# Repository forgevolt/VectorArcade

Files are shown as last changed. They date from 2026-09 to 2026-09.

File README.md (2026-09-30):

# VectorArcade

Two handheld game consoles, one firmware. VectorArcade plays **Lunar Lander** and
**Asteroids** - the two vector arcade classics of 1979 - redrawn as line graphics on an
ESP32 with a colour TFT, an analog joystick and I2S sound. The same sketch builds for both
consoles: the **LittleGameConsole** (320x240) and the **TintinRocketShooter** (240x240), whose
housing is modelled on the moon rocket from the Tintin comics.

<table>
  <tr>
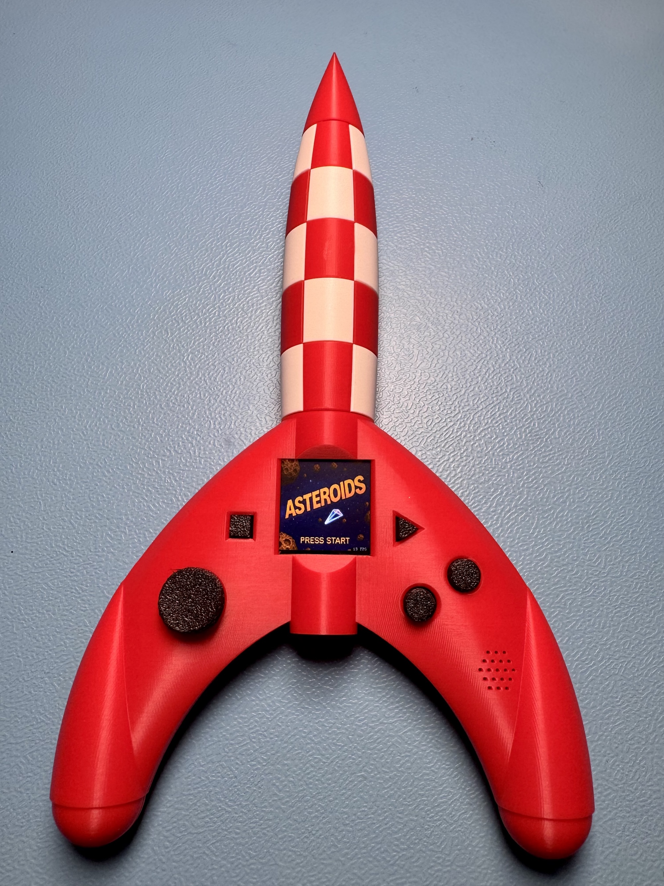
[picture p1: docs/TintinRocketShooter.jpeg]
TintinRocketShooter
    <td></td>
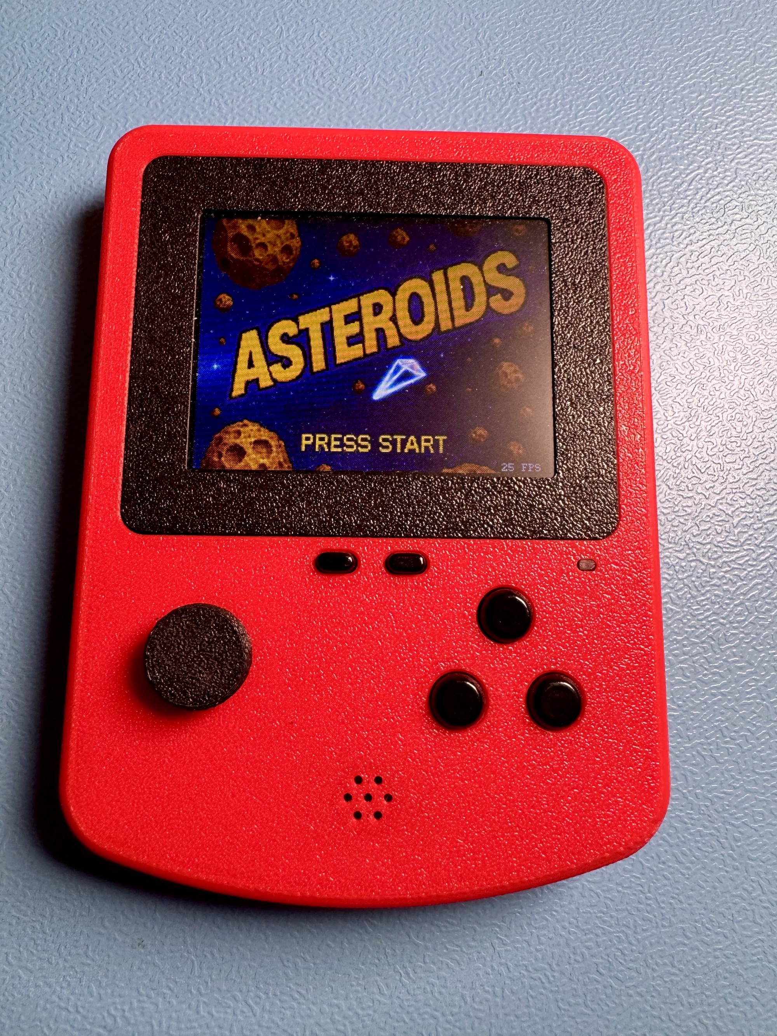
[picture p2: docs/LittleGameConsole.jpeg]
LittleGameConsole
    <td></td>
  </tr>
  <tr>
    <td align="center">TintinRocketShooter</td>
    <td align="center">LittleGameConsole</td>
  </tr>
</table>

## What it does

- **Lunar Lander.** Land the Eagle on one of the pads before the fuel runs out. Four pads
  per attempt carry a bonus of 2x to 5x, and the landing is scored great, good or hard. The
  lunar surface scrolls endlessly in both directions, and the view zooms in close to the
  ground. On the TintinRocketShooter the engine can also be throttled by tilting the console.
- **Asteroids.** Rotate, thrust, fire and jump into hyperspace. Asteroids split when hit,
  a saucer appears from time to time and shoots back, and the high score is kept.
- **Configuration menu.** Joystick calibration, IMU calibration (TintinRocketShooter), sound
  volume, and a wipe-and-reset that clears every stored setting. An FPS display can be
  switched on from the main menu.
- **Sound.** Seven clips mixed by [SoundEngine](https://github.com/forgevolt/SoundEngine),
  loaded from the flash filesystem into PSRAM at startup, or linked into the firmware for
  boards without PSRAM.
- **Battery.** A MAX17048 fuel gauge drives the battery indicator in the menu.
- **Fixed frame rate.** The games run at a steady 25 frames per second.

## Controls

| | Menu | Lunar Lander | Asteroids |
| --- | --- | --- | --- |
| Joystick | up/down: choose | up: engine thrust | left/right: rotate |
| A | open | rotate left | fire |
| B | - | rotate right | thrust |
| Aux | - | abort landing | hyperspace |
| Start | open | start a game | start a game |
| Sel | back | quit the game | quit the game |
| Joystick button | open | - | - |

The TintinRocketShooter has no Aux button: **Start** takes its place during a game (abort
landing, hyperspace). Before a Lunar Lander game, **A** adds fuel and **Start** begins; on the
TintinRocketShooter, left/right first chooses between the joystick and tilting the console
("Gyro") as the throttle.

## Hardware

| Part | LittleGameConsole | TintinRocketShooter |
| --- | --- | --- |
| Controller | ESP32-PICO-MINI-02U, 8 MB flash, 2 MB PSRAM | ESP32-PICO-V3-02, 8 MB flash, 2 MB PSRAM |
| Display | ST7789 320x240, SPI, switched backlight | ST7789 240x240, SPI |
| Buttons | A, B, Aux, Sel, Start, joystick button | A, B, Sel, Start, joystick button |
| Joystick | 2-axis analog | 2-axis analog |
| IMU | - | MPU6050, I2C |
| Fuel gauge | MAX17048, I2C | MAX17048, I2C |
| Charge sense | - | USB present and charger status |
| Audio | MAX98357A, I2S | MAX98357A, I2S |

### Wiring

`software/VectorArcade/boards/<console>/PinMap.h` is the single source of truth for every
GPIO; this table mirrors both.

| Function | Signal | LittleGameConsole | TintinRocketShooter |
| --- | --- | --- | --- |
| Display (SPI) | SCK | 14 | 14 |
| Display (SPI) | MOSI | 12 | 12 |
| Display | DC | 15 | 15 |
| Display | RESET | 13 | 13 |
| Display | backlight | 2 | - |
| I2C (fuel gauge, IMU) | SDA | 22 | 22 |
| I2C (fuel gauge, IMU) | SCL | 21 | 21 |
| I2S (audio) | DOUT | 8 | 8 |
| I2S (audio) | BCLK | 5 | 5 |
| I2S (audio) | LRC / word select | 19 | 19 |
| Button | A | 26 | 4 |
| Button | B | 25 | 7 |
| Button | Aux | 4 | - |
| Button | Sel | 7 | 36 |
| Button | Start | 20 | 20 |
| Joystick | button | 33 | 38 |
| Joystick | X | 37 | 32 |
| Joystick | Y | 38 | 37 |
| Power sense | USB present | - | 26 |
| Power sense | charger status | - | 25 |

Three of these pins need care when wiring or re-laying out a board:

- **GPIO 12 is the flash-voltage strapping pin.** It is latched at reset, and high selects
  1.8 V flash - with 3.3 V flash the board then does not boot. SPI MOSI idles low, which is
  why it works here. Do not fit a pull-up to this line.
- **GPIO 2 must be low or floating at reset**, or the serial bootloader cannot be entered.
  On the LittleGameConsole it switches the backlight, and `setup()` drives it low before
  anything else runs.
- **GPIO 34 to 39 have no internal pull-ups.** On the TintinRocketShooter, Sel (36) and the
  joystick button (38) rely on external pull-ups.

## Repository layout

| | |
|---|---|
| [`software/`](software) | The firmware sketch, and the tools for its sound clips and images |
| [`hardware/`](hardware) | PCBs: EasyEDA projects, Gerbers, schematics |
| [`mechanics/`](mechanics) | Housings: Fusion source, STLs, print profiles |
| [`docs/`](docs) | Photographs of the two consoles |

Each of those has its own README.

## Getting started

1. Install the esp32 core and the libraries (see **Building** below).
2. In `software/VectorArcade/`, copy `BoardSelect.h.template` to `BoardSelect.h` and select
   your console in it.
3. Open `software/VectorArcade/VectorArcade.ino` in the Arduino IDE.
4. Select board *ESP32 Dev Module* with the settings in the table below.
5. Upload, then upload the sound clips once - see
   [Setting up a new console](software/README.md#setting-up-a-new-console).

## Building

Built with the **Arduino IDE** and the **esp32 core 2.0.17** by Espressif Systems (Boards
Manager). The core is pinned on purpose: FabGL, the graphics library, does not build on core
3.x ([FabGL issue #385](https://github.com/fdivitto/FabGL/issues/385)).

### Libraries

Install through the Arduino library manager. These are the versions it is built and tested
against:

| Library | Version | Note |
| --- | --- | --- |
| FabGL | 1.0.9 | display driver, canvas and fonts - GPL-3.0, see [THIRD_PARTY.md](THIRD_PARTY.md) |
| [SoundEngine](https://github.com/forgevolt/SoundEngine) | 1.1.0 | I2S mixing and playback; 1.1.0 is the first version that builds on core 2.x |
| Bounce2 | 2.71 | button debouncing |
| Streaming | 6.3.0 | the `Serial <<` logging |
| Adafruit MAX1704X | 1.0.3 | the fuel gauge |
| Adafruit BusIO | 1.17.4 | installed with Adafruit MAX1704X |
| MPU6050_light | 1.2.1 | by rfetick - the IMU of the TintinRocketShooter; several MPU6050 libraries exist, this is the one used here |

LittleFS, Wire, SPI and Preferences come with the core.

### Board settings

Select **ESP32 Dev Module** and change these settings - four of them differ from the
defaults, and a wrong one fails silently rather than with an error:

| Setting | Value | Note |
| --- | --- | --- |
| Board | **ESP32 Dev Module** | |
| Flash Size | **8MB (64Mb)** | the default is 4MB |
| Flash Frequency | **80MHz** | the default is 40MHz, which halves the flash read speed |
| Flash Mode | **QIO** | |
| PSRAM | **Enabled** | needed for the sound clips on LittleFS |
| Partition Scheme | **8M with spiffs (3MB APP/1.5MB SPIFFS)** | only sets the upload limit; `partitions.csv` defines the layout |
| CPU Frequency | 240MHz | default |
| Erase All Flash Before Sketch Upload | Disabled | default; enabled, it deletes the uploaded sound clips |

`software/VectorArcade/partitions.csv` sits in the sketch folder, and the core uses it in
preference to the Partition Scheme menu: a 6 MB application partition, no OTA, and a
1.875 MB LittleFS partition for the sound clips. The IDE still takes the maximum upload size
from the menu, so uploads are capped at **3,342,336 bytes**; the firmware is about 1.4 MB.
Details, and what to change for boards without PSRAM or with 4 MB flash, are in
[software/README.md](software/README.md).

### Compiler warnings

`software/VectorArcade/build_opt.h` switches on more warnings than the core does:

```
-Wall
-Wextra
-Wdouble-promotion
-Wsign-compare
```

`-Wdouble-promotion` matters on the ESP32, which has no hardware double: it catches float
maths that silently turns into slow double maths. The IDE setting *Compiler warnings: None*
passes `-w`, which hides all of them; to see them, raise that setting or build with
`arduino-cli compile --warnings all`. The firmware builds without a warning from its own
sources; the remaining ones come from the libraries.

## How it runs

One frame every 40 ms (25 FPS): the active game steps its objects by a fixed 40 ms, draws
the frame into FabGL's back buffer, and the buffer is sent to the display over SPI in one
go. That transfer is the largest part of the frame - about 33 ms of the 40 on the
LittleGameConsole - so the other work is kept short, and the background tasks run on the
other core:

| Task | Priority | Core | Rate | Does |
| --- | --- | --- | --- | --- |
| `loopTask` | 1 | 1 | 25 Hz | game logic, joystick, drawing, the frame transfer |
| sound | 1 | 0 | - | mixes and queues the next audio chunk (owned by SoundEngine) |
| `processEvents` | 0 | 0 | 200 Hz | reads and debounces the buttons |

The joystick is read once per frame in the game loop, averaging several ADC readings per
axis against the ESP32's ADC noise. Settings - calibration, volume, high scores, the FPS
display - are stored with Preferences in the `nvs` partition.

## Acknowledgements and trademarks

- **Lunar Lander** and **Asteroids** were released by Atari in 1979. VectorArcade is an
  independent reimplementation, not affiliated with or endorsed by Atari, which owns the
  names. The lunar surface and its landing zones follow the original game's, measured from
  screenshots of it.
- **Tintin** and his moon rocket are creations of Hergé. The TintinRocketShooter's housing
  is an original design based on the rocket from the comics -
  [A lunar project: Tintin's rocket](https://www.tintin.com/en/news/6343/a-lunar-project-tintins-rocket)
  and [The speaking vignette: Tintin's rocket](https://www.tintin.com/en/news/6351/the-speaking-vignette-tintins-rocket).
  The project is not affiliated with or endorsed by the rights holders.
- **Fabrizio Di Vittorio** - [FabGL](https://github.com/fdivitto/FabGL), which does all the
  drawing.
- The sound effects come from [Pixabay](https://pixabay.com/sound-effects/); see
  [THIRD_PARTY.md](THIRD_PARTY.md).

## Licence

MIT - see [LICENSE](LICENSE). The firmware links FabGL, which is GPL-3.0, so a built
firmware image is a combined work under GPL-3.0; the source files here stay MIT, except
`software/tools/img2bitmap.py`, which comes from FabGL. Details, and the licences of all
libraries and assets, are in [THIRD_PARTY.md](THIRD_PARTY.md).

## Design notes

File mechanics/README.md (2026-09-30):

# Housings

The housings of both consoles: Fusion source, print-ready meshes, and the Bambu Studio
projects they were printed from.

| Path | Contents |
|---|---|
| `cad/LittleGameConsole.f3z` | The Fusion source of the LittleGameConsole, as an archive containing the whole assembly |
| `cad/TintinRocketShooter.f3d` | The Fusion source of the TintinRocketShooter |
| `stl/LittleGameConsole.stl` | Print-ready mesh of the LittleGameConsole: 7 bodies in one file, 93 x 127 x 23 mm overall |
| `stl/TintinRocketShooter.stl` | Print-ready mesh of the TintinRocketShooter: 13 bodies in one file, 150 x 45 x 244 mm overall |
| `print-profiles/LittleGameConsole/` | Bambu Studio projects, one per part |
| `print-profiles/TintinRocketShooter/` | Bambu Studio projects, one per part or group of parts, some in two materials |

The TintinRocketShooter's housing is an original design based on Tintin's moon rocket from
Hergé's comics; the red and white checks are printed as separate tiles.

## The parts

Taken from the projects in `print-profiles/`. Every project was sliced for one Bambu Lab
printer and nozzle, named in the table.

### LittleGameConsole

| Project | Part | Printer, nozzle | Layer | Walls | Infill | Material |
|---|---|---|---|---|---|---|
| `LittleGameConsole_Top0.2.3mf` | top shell | H2D, 0.2 mm | 0.10 mm | 4 | 15% | PLA |
| `LittleGameConsole_Bottom_90Deg.3mf` | bottom shell, standing on edge (90°) | H2D, 0.4 mm | 0.12 mm | 4 | 15% | PETG-CF |
| `LittleGameConsole_Bottom_30Deg.3mf` | bottom shell, tilted (30°) | H2D, 0.4 mm | 0.16 mm | 2 | 15% | PETG-CF |
| `Buttons.3mf` | action and control buttons | H2D, 0.4 mm | 0.12 mm | 4 | 50% | ABS |

The two bottom-shell projects are the same part in two print orientations; print one of them.

### TintinRocketShooter

| Project | Part | Printer, nozzle | Layer | Walls | Infill | Material |
|---|---|---|---|---|---|---|
| `TinTinRocket-Lower-H2D-ABS-GF.3mf` | lower body | H2D, 0.4 mm | 0.12 mm | 6 | 15% | ABS-GF |
| `TinTinRocket-Lower-H2D-PLA-GF.3mf` | lower body | H2D, 0.4 mm | 0.12 mm | 6 | 15% | ABS-GF (see below) |
| `TinTinRocket-Upper-H2D-ABS-GF ABS-Support.3mf` | upper body | H2D, 0.4 mm | 0.12 mm | 6 | 15% | ABS-GF |
| `TinTinRocket-Upper-H2D-PLA-GF Support.3mf` | upper body | H2D, 0.4 mm | 0.12 mm | 6 | 15% | PLA-GF |
| `TinTinRocket-Top-H2D-ABS-GF ABS-Support.3mf` | top | H2D, 0.4 mm | 0.08 mm | 6 | 15% | ABS-GF |
| `TinTinRocket-Top-H2D-PLA-GF Support.3mf` | top | H2D, 0.4 mm | 0.12 mm | 6 | 15% | PLA-GF |
| `RocketShooterLower.3mf` | lower body | X1 Carbon, 0.2 mm | 0.06 mm | 6 | 15% | PLA |
| `RocketShooterUpper.3mf` | upper body | X1 Carbon, 0.2 mm | 0.06 mm | 6 | 15% | PLA |
| `RocketTop.3mf` | top | X1 Carbon, 0.2 mm | 0.06 mm | 6 | 15% | PLA |
| `Tiles.3mf` | the checker tiles, rows 1 to 5 | X1 Carbon, 0.2 mm | 0.06 mm | 6 | 15% | PLA |
| `SelectStartBtn.3mf` | Select and Start buttons | X1 Carbon, 0.2 mm | 0.06 mm | 6 | 15% | PLA |
| `JoyTopCover.3mf` | joystick cap | X1 Carbon, 0.4 mm | 0.2 mm | 2 | 15% | TPU |
| `Battery.3mf` | battery end pieces, plus and minus | X1 Carbon, 0.2 mm | 0.06 mm | 6 | 15% | PLA |
| `Stand.3mf` | stand | X1 Carbon, 0.4 mm | 0.12 mm | 3 | 15% | PLA |

The body - lower part, upper part and top - comes in two sets of projects: `TinTinRocket-*`
for an H2D with a 0.4 mm nozzle, in glass-filled ABS or PLA, and `RocketShooter*` /
`RocketTop` for an X1 Carbon with a 0.2 mm nozzle, in PLA. Print one set.

## Opening the CAD

`LittleGameConsole.f3z` is a Fusion archive rather than a single `.f3d` part - open it with
*File → Open* in Fusion, which unpacks the design and its components.
`TintinRocketShooter.f3d` opens directly.

There is no STEP export here. If you want to modify a housing without a Fusion licence, a
STEP export is the thing to ask for; the STLs are fine for printing but carry no editable
geometry.

## About `print-profiles/`

These are Bambu Studio projects: a full copy of the mesh plus the slicer state, so each is
specific to one printer and one filament, and the larger ones run to tens of megabytes. They
are here as a reference for anyone with the same machine. On any other printer, the STLs
plus the tables above carry the same information in a form your own slicer can use.

**This folder still needs a cleanup.** It holds the projects as they were used, and not all
of them are consistent yet:

- `TinTinRocket-Lower-H2D-PLA-GF.3mf` is currently an exact copy of the ABS-GF project, so
  it prints in ABS-GF too. A PLA-GF project for the lower body is still to come.
- The TintinRocketShooter's body is covered twice, by the `TinTinRocket-*` projects for the
  H2D and the `RocketShooter*` / `RocketTop` projects for the X1 Carbon.
- Some file names contain spaces, and the names do not follow one pattern.

Until then, check part, printer and filament in Bambu Studio before printing.

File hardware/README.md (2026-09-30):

# PCBs

The custom boards of both consoles: everything needed to have them made, and to change them.

| Path | Contents |
|---|---|
| `easyeda/ProPrj_LittleGameConsole_2026-09-30.epro2` | LittleGameConsole: the editable EasyEDA Pro project - schematic and layout |
| `easyeda/ProPrj_TintinRocketShooter_2026-09-30.epro2` | TintinRocketShooter: the same |
| `gerber/Gerber_LittleGameConsolePCB_2026-09-30.zip` | LittleGameConsole: fabrication files, zipped as a fab expects them |
| `gerber/Gerber_PCB_TintinRocketShooter_2026-09-30.zip` | TintinRocketShooter: the same |
| `schematic_LittleGameConsole.pdf` | LittleGameConsole: the schematic as a document, readable without EasyEDA (6 sheets) |
| `schematic_TintinRocketShooter.pdf` | TintinRocketShooter: the same (7 sheets) |

The EasyEDA projects and the Gerber archives carry their export date in the file name, so a
later revision can sit beside these rather than silently replacing them.

## Ordering a board

Upload the Gerber archive of the console as it is - a standard Gerber and drill set. Nothing
in the design depends on a particular fab.

If you revise a layout, tag this repository when you order from it. A year later, "which
files made the board in my hand" then has an answer the tree alone cannot give.

## What is on the boards

From the schematics, the parts worth naming:

| Function | LittleGameConsole | TintinRocketShooter |
|---|---|---|
| Controller | ESP32-PICO-MINI-02U | ESP32-PICO-V3-02 |
| USB to serial, for flashing and the Serial Monitor | CP2102N | CP2102N |
| ESD protection of the USB lines | USBLC6-2SC6 | USBLC6-2SC6 |
| Li-ion charger | MCP73831 | MCP73831 |
| 3.3 V regulator | LD39200PUR, 2 A LDO | NCP167BMX330TBG, LDO |
| Battery fuel gauge | MAX17048 | MAX17048 |
| I2S class-D amplifier | MAX98357A | MAX98357A |

The display, the joystick and the buttons connect to the board; the GPIO of every signal is
in the wiring table of the top-level README, which mirrors each console's `PinMap.h`. The
same section names the three pins that need care in a new layout: GPIO 12 (flash voltage),
GPIO 2 (boot mode) and the input-only GPIO 34 to 39.

The schematic is the authority for what was actually built.

## Known errors on the TintinRocketShooter board

- **The battery connector sits too close to the display** and cannot be fitted. The
  battery's wires are soldered directly to the board instead.
- **The ESP32 reset button sits too close to the display**, which would keep it pressed. It
  is not fitted.
- **The joystick is exposed to electrostatic discharge without its cap.** Touching the bare
  joystick can discharge into the board, and the firmware then hangs. Always fit the cap
  (`JoyTopCover` in [`mechanics/`](../mechanics)). A revision should add ESD protection to
  the joystick lines, or ground the joystick's metal housing.

A revision of this board should move the battery connector and the reset button clear of
the display.

## Ideas for the next revision

None of these is a fault - both boards work as built. They are traps for whoever reworks or
re-lays-out a board, and improvements collected while writing the firmware.

### Pins

1. **GPIO 12 - flash voltage.** GPIO 12 is latched at reset and selects the flash voltage;
   high means 1.8 V, and with 3.3 V flash the board then does not boot. Today it carries SPI
   MOSI, which idles low. Keep it free of anything that can pull it high - or fix the
   voltage for good with `espefuse.py set_flash_voltage 3.3V`, after checking with
   `espefuse.py summary` whether the module has already done so (`XPD_SDIO_FORCE`). Burning
   the eFuse is irreversible and must match the module's flash.
2. **Display bus on its native pins.** The ST7789 is driven at 40 MHz because MOSI on
   GPIO 12 is not one of HSPI's native pins, which routes the whole bus through the GPIO
   matrix. Swapping MOSI and RESET (12 ↔ 13) puts every signal on its native pin and allows
   80 MHz - raising the full-frame limit from about 32 to about 65 frames per second at
   320x240. 80 MHz overclocks the panel (the ST7789 specifies 62.5 MHz), so test it on
   several units. After the swap, RESET sits on GPIO 12: a pull-up on the panel's reset
   line would then stop the board from booting, so decide this together with item 1.
3. **I2S clocks off GPIO 5 and 19.** These are the Arduino defaults for SPI `SS` and `MISO`.
   Nothing calls `SPI.begin()` today, but a library that does would take over both I2S
   clocks.
4. **GPIO 2 and the backlight** (LittleGameConsole). GPIO 2 must be low or floating at reset
   for the serial bootloader. Driving the backlight from it works because `setup()` pulls it
   low first; a backlight circuit with a pull-up would break flashing.
5. **Buttons on GPIO 34 to 39** (TintinRocketShooter). These pins have no internal pull-ups,
   so Sel (36) and the joystick button (38) depend on external resistors. Keep them
   deliberately, or move the buttons to pins with internal pull-ups.

The I2C pins 21 and 22 are the reverse of the Arduino defaults. The firmware handles this
by calling `Wire.begin(cI2C_SDA, cI2C_SCL)` before any library starts the bus; a board that
uses the default order would not depend on that.

### Charging

6. **Charge sense for the LittleGameConsole.** The TintinRocketShooter shows a "+" at the
   battery while charging, from two signals: USB present, and the charger's STAT output.
   The LittleGameConsole has neither - its GPIO 25 and 26 are buttons. A revision needs two
   free pins, the analog one on ADC1 (GPIO 32 to 39). The firmware is ready: add the pins to
   `PinMap.h` and set `BOARD_HAS_CHARGE_SENSE()` to 1 in `Board.h`. Whether the MAX17048's
   own charge-rate reading can replace this without a hardware change is still being
   tested.
7. **Read all three states of STAT.** The MCP73831's STAT output is low while charging, high
   when charging is complete, and high-impedance with no input power or no battery. A
   digital input cannot tell high-impedance from high. Bias the sense node with two
   100 kΩ resistors to 3.3 V and ground, feed STAT through a **75 kΩ series resistor**, and
   add 100 nF to ground; one ADC reading then gives about 0.99 V (charging), 1.65 V
   (high-impedance) or 3.0 V (complete). The series resistor matters: the charger runs
   from USB, so STAT high is about 5 V, beyond the ESP32's 3.6 V maximum. Schematic:
   [`STAT_TriState.svg`](STAT_TriState.svg). On the current TintinRocketShooter board,
   check whether STAT already reaches GPIO 25 through a divider or series resistor.

STAT three-state sense

### Larger changes

8. **ESP32-S3 with PSRAM.** Its DMA can read PSRAM, so a full-screen frame buffer in PSRAM
   could be sent to the display while the next frame is drawn; the display bus goes on
   native pins as in item 2; and it brings a faster core, a better ADC and native USB. The
   cost: FabGL does not support the S3, so the graphics move to TFT_eSPI or LovyanGFX, and
   the pin map starts over - different strapping pins (0, 3, 45, 46), native USB on GPIO
   19 and 20, octal PSRAM reserving GPIO 35 to 37, ADC1 on GPIO 1 to 10. The esp32 core
   2.0.17 supports the S3.
9. **A dedicated ADC for the joystick.** The ESP32's ADC is flat near both ends, bent above
   about 2.5 V, noisy, and not ratiometric to the potentiometers' supply; the firmware
   compensates with calibration, averaging and an expo curve. An **MCP3208** (or the
   4-channel MCP3204) on its own SPI pins, with `VREF` tied to the potentiometer supply,
   gives 12 linear, ratiometric bits in microseconds, plus spare channels for the battery
   or the STAT node. An **ADS1115** needs no new pins - it joins the I2C bus at 0x48 to
   0x4B - but converts at most about 400 times a second per axis and adds traffic to the
   bus the IMU is read on. On an ESP32-S3, measure the built-in ADC first. **Hall-effect
   joysticks** fix the other half of the problem - wear, drift and dead spots of the
   potentiometers - and work with either choice. In the firmware, `Joystick2Axis` reads
   through a single function, so an external ADC is a second implementation behind a
   `Board.h` setting.

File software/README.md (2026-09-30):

# Software

| Path | What |
|---|---|
| `VectorArcade/` | The firmware. One sketch for both consoles |
| `tools/wav2h.py` | Turns the WAV files into headers for the linked build, and writes their fingerprint |
| `tools/img2bitmap.py` | Converts an image into a FabGL `Bitmap` in C++ source, as used for the splash screens. From FabGL, GPL-3.0 |

## `VectorArcade/` - the firmware

| Files | Responsibility |
| --- | --- |
| `VectorArcade.ino` | setup of display, fuel gauge, IMU, filesystem and menu; the 25 FPS loop |
| `Menu.*`, `MenuItem.*`, `MenuPage.*` | the main menu, its entries and the configuration page |
| `DisplayObject.*` | base class of everything on screen, text and instruction helpers |
| `InputController.*`, `Joystick2Axis.*` | the buttons, debounced in their own task, and the joystick |
| `LunarLander.*`, `Eagle.*`, `LunarSurface.*`, `Camera.h`, `LunarLanderSounds.h` | Lunar Lander: game states, the lander, the endless surface, the scrolling and zooming view |
| `Asteroids.*`, `AsteroidsGameObjects.*`, `AsteroidsSounds.h` | Asteroids: game states, ship, shots, asteroids and saucer |
| `SoundClips.*` | loads the clips from LittleFS and checks their fingerprint |
| `JoystickCalibration.*`, `IMUCalibration.*`, `SoundVolume.*`, `WipeAndReset.*`, `FPSToggle.*` | the configuration entries |
| `BatteryStatus.*`, `IMUStatus.*` | the battery indicator and the IMU readout in the menu |
| `MathUtilities.*` | 2D and 3D vector maths |
| `Version.h` | the firmware version |
| `BoardSelect.h.template` | the console to build for, and the sound source (see below) |
| `Board.h`, `PinMap.h`, `Layout.h`, `AsteroidsSplash.h` | forward to the selected console's files in `boards/` |
| `boards/<console>/` | per console: GPIO (`PinMap.h`), display and features (`Board.h`), screen positions (`Layout.h`), the Asteroids splash image |
| `data/` | the sound clips as WAV files, and their fingerprint `sounds.id` |
| `sounds/` | the same clips as headers, generated by `wav2h.py` |
| `build_opt.h` | extra compiler warnings |
| `partitions.csv` | 6 MB app + 1.875 MB LittleFS; overrides the Tools menu |

### Choosing the console

The console is selected in `BoardSelect.h`. That file is not tracked by git, so switching
consoles never shows up as a change. After cloning, copy `BoardSelect.h.template` to
`BoardSelect.h` and set exactly one of these to 1:

```cpp
#define BOARD_IS_LITTLEGAMECONSOLE()    1
#define BOARD_IS_TINTINROCKETSHOOTER()  0
```

The same file holds one build option, where the sound clips come from:

```cpp
#define SOUNDS_FROM_LITTLEFS()          1
```

- **1** (default): the WAV files are read from the `littlefs` partition into PSRAM at
  startup. The firmware is smaller, and a firmware upload does not rewrite the sounds. Needs
  PSRAM, and the files uploaded once (below).
- **0**: the clips are linked into the firmware from `sounds/*.h`. Works without PSRAM and
  without a file upload, at about 0.4 MB more firmware.

The build prints which console and which sound source it is building for.

### Partition table

`partitions.csv` sits in the sketch folder, and the core uses it in preference to the
Partition Scheme menu:

| Name | Type | Offset | Size | |
| --- | --- | --- | --- | --- |
| nvs | data | 0x9000 | 20 KB | stored settings: calibration, volume, high scores |
| otadata | data | 0xE000 | 8 KB | |
| factory | app | 0x10000 | 6 MB | the firmware, single slot, no OTA |
| littlefs | data | 0x610000 | 1.875 MB | the sound clips |
| coredump | data | 0x7F0000 | 64 KB | a crash dump, readable with `espcoredump.py` |

The `littlefs` partition keeps the subtype `spiffs`: ESP-IDF 4.4, which core 2.0.17 is built
on, has no LittleFS subtype, and LittleFS finds the partition by its label.

The Partition Scheme menu still matters for one thing: the IDE takes the maximum upload size
from it, so uploads are capped at **3,342,336 bytes** although the partition holds 6 MB.

### Setting up a new console

1. Choose the console as above, compile and upload. The upload writes the partition table
   from `partitions.csv` together with the firmware.
2. Let it boot once with the Serial Monitor open (115200 baud). The empty `littlefs`
   partition cannot be mounted yet, so the firmware formats it and reports
   `LittleFS: partition cannot be mounted - formatting it as LittleFS`. A partition that
   holds another filesystem (SPIFFS, FAT) is formatted the same way, and its files are lost.
3. Upload the contents of `data/` - the seven WAV files and `sounds.id` - into the root of
   the LittleFS partition, for example with the browser tool
   [ESPConnect](https://github.com/thelastoutpostworkshop/ESPConnect). File names are
   case-sensitive. Then restart.
4. At startup the firmware compares `sounds.id` with the fingerprint compiled into it and
   reports `LittleFS: sound files match`, or tells you to upload `data/` again.

Later firmware uploads keep the files, as long as *Erase All Flash Before Sketch Upload*
stays disabled.

### Changing a sound

`data/*.wav` is the single source of the sound clips: 16-bit PCM WAV, mono, 11,025 Hz.
After changing, adding or removing a file, run

```
python3 software/tools/wav2h.py
```

It regenerates `sounds/*.h` for the linked build and writes a new fingerprint into
`data/sounds.id` and `sounds/SoundsId.h`. Then rebuild, and upload `data/` again, including
`sounds.id`. `wav2h.py --check` only reports whether anything is out of date. The script
needs nothing beyond the Python 3 standard library.

### Boards without PSRAM, or with 4 MB flash

- Without PSRAM, build with `SOUNDS_FROM_LITTLEFS()` set to 0. A LittleFS build without
  PSRAM is refused at compile time.
- `partitions.csv` is laid out for **8 MB** flash, so a 4 MB module needs a different
  partition table. The linked build is about 1.84 MB, so on 4 MB it fits only a partition
  scheme with a ~3 MB application ("Huge APP", no OTA), not the default 1.25 MB one.
- Replace or remove `partitions.csv` accordingly. While it is present it overrides the
  Partition Scheme menu, and the IDE's size check still uses the menu's maximum, so select a
  scheme whose application size matches.

## `tools/img2bitmap.py` - images for the display

The firmware cannot read image files: every picture is compiled in as a FabGL `Bitmap`, a
byte array plus its size and pixel format. `img2bitmap.py` is FabGL's own converter,
included unmodified. It needs Python 3 and Pillow (`pip install pillow`):

```
python3 software/tools/img2bitmap.py AsteroidsSplash.png -s 320 240 -f1 > AsteroidsSplash.h
```

| Option | |
|---|---|
| `-s width height` | resize to this size - 320 240 for the LittleGameConsole, 240 240 for the TintinRocketShooter |
| `-f0` / `-f1` / `-f2` | pixel format: RGBA2222 (64 colours, the default), RGBA8888, or 1-bit monochrome |
| `-d` | dither, for RGBA2222 |
| `-t x y` | take the colour of this pixel as transparent |
| `-o0` / `-o1` | output as C++ source (the default) or as a plain hex string |

The array and the bitmap are named after the input file, so `AsteroidsSplash.png` gives
exactly the `AsteroidsSplash_data` and `AsteroidsSplash` that `boards/<console>/AsteroidsSplash.h`
declares. The splash screens use RGBA8888: their colour gradients band or turn grainy in
64 colours.

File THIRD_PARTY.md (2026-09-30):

# Third-party licences

The files in this repository are MIT licensed (see LICENSE), except
`software/tools/img2bitmap.py`, which comes from FabGL (below). The firmware builds against
the libraries below. None of them are redistributed here - each is installed
through the Arduino library manager or comes with the esp32 core, and keeps its own licence.

| Library | Licence | Used for |
| --- | --- | --- |
| FabGL | GPL-3.0 | the display driver, the canvas and the fonts |
| SoundEngine | MIT | I2S mixing and playback |
| Bounce2 | MIT | button debouncing |
| Streaming | LGPL-2.1-or-later | the `Serial <<` logging |
| Adafruit MAX1704X | BSD | the battery fuel gauge |
| Adafruit BusIO | MIT | I2C access for the fuel gauge library |
| MPU6050_light | MIT | the IMU of the TintinRocketShooter |
| esp32 core 2.0.17 | LGPL-2.1 (Arduino core), Apache-2.0 (ESP-IDF) | the platform, including LittleFS, Wire, SPI and Preferences |

SoundEngine is written for this project and published separately, under the same MIT
licence as this repository: [SoundEngine](https://github.com/forgevolt/SoundEngine).

## FabGL

[FabGL](https://github.com/fdivitto/FabGL) by Fabrizio Di Vittorio does all the drawing:
the ST7789 driver, the double-buffered canvas and the fonts. It is licensed under
**GPL-3.0**.

The firmware cannot be built without linking FabGL, so a **built firmware image is a
combined work governed by GPL-3.0**, even though the firmware's own files are MIT.
Unlike the LGPL (see Streaming below), the GPL has no relinking exception that would let the
binary keep a more permissive licence. In practice:

| | |
| --- | --- |
| The firmware source in this repository | MIT. FabGL itself is not redistributed here, only named as a dependency. |
| A built `.bin`, or a console with the firmware on it | Conveyed under GPL-3.0. The corresponding source is this public repository together with FabGL's own. |
| Reusing files from this repository elsewhere | MIT, unaffected - as long as FabGL is not part of what is carried across. |

`software/tools/img2bitmap.py` is FabGL's image converter (`tools/img2bitmap/` in the
FabGL repository), included unmodified. It is part of FabGL and therefore GPL-3.0, not MIT;
it is a separate tool that runs on the PC, so it does not become part of the firmware.

FabGL's own notices stay intact, and nothing in this repository describes FabGL as MIT.

## Streaming

`Streaming.h` by Mikal Hart is used for logging throughout the firmware. The LGPL does not
affect the licence of this project, but it asks that anyone who receives a binary can relink
it against a modified version of the library. Complete source is published here, so a
recipient can modify Streaming and rebuild.

## Sound effects

The seven clips in `software/VectorArcade/data/` (and the headers generated from them in
`software/VectorArcade/sounds/`) come from [Pixabay](https://pixabay.com/sound-effects/),
under the [Pixabay Content License](https://pixabay.com/service/license-summary/). It allows
use and modification, commercially too, without attribution; it does not allow selling or
distributing a clip on its own. Here each one is part of the game, and all of them were
trimmed, looped and re-encoded for it.

| Clip | Source |
| --- | --- |
| `RocketEngine.wav` | [Looking straight into a burning rocket engine](https://pixabay.com/sound-effects/film-special-effects-sfx-looking-straight-into-a-burning-rocket-engine-sound-effect-283448/) |
| `Explosion.wav`, `FuelAlarm.wav`, `Pew.wav`, `PewSaucer.wav`, `SaucerAlert.wav`, `SmallExplosion.wav` | Pixabay; the individual pages are no longer known |

The menu click, beep and signal sounds are generated by SoundEngine.

## Splash screens

The Asteroids splash screens (`software/VectorArcade/boards/*/AsteroidsSplash.h`) are
AI-generated artwork made for this project, with the game's own vector ship drawn into
them. They are covered by the MIT licence of this repository.

## Names

Lunar Lander and Asteroids are names of arcade games released by Atari in 1979; Tintin and
his moon rocket are creations of Hergé. VectorArcade is an independent project, not
affiliated with or endorsed by either rights holder. The games are reimplemented from their
published gameplay, and the TintinRocketShooter's housing is an original design based on the
rocket from the comics.

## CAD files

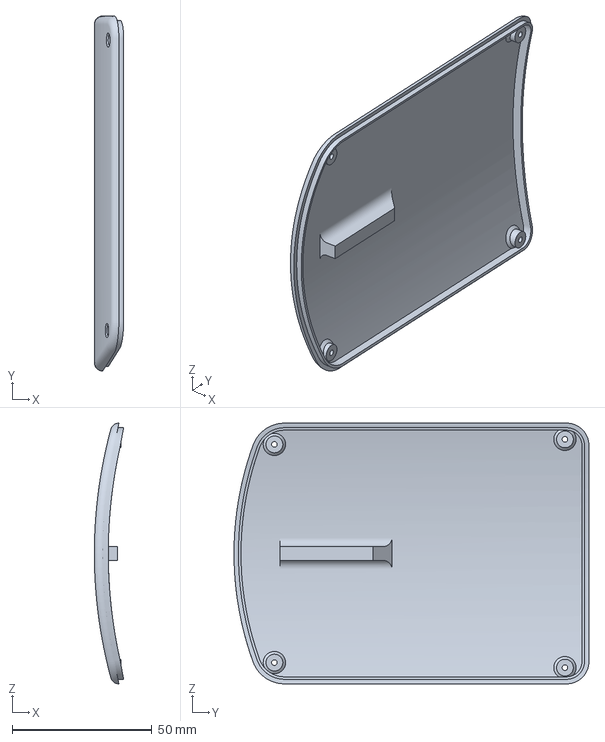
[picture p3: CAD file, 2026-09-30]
mechanics/print-profiles/LittleGameConsole/LittleGameConsole_Bottom_90Deg.3mf
10.5 x 126.9 x 93.2 mm

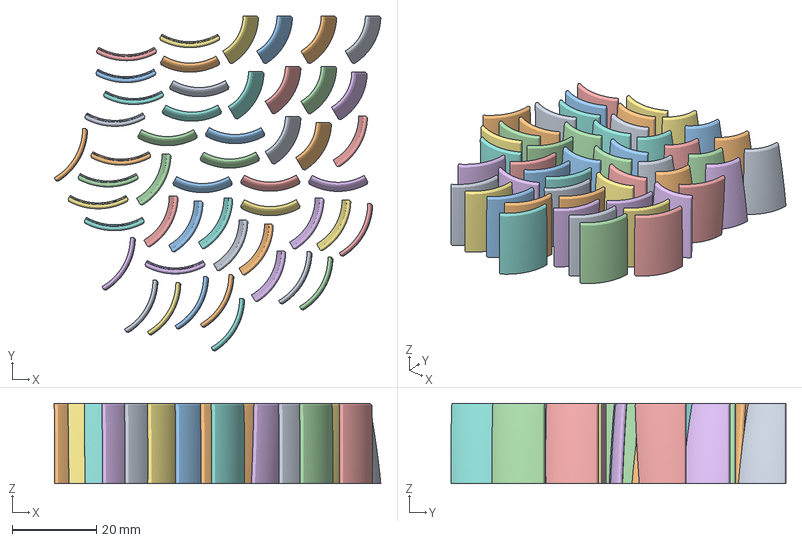
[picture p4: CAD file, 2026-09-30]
mechanics/print-profiles/TintinRocketShooter/Tiles.3mf
77.6 x 79.5 x 19.0 mm
TileRow1.step x 10
TileRow2.step x 10
TileRow5.step x 10
TileRow4.step x 10
TileRow3.step x 10

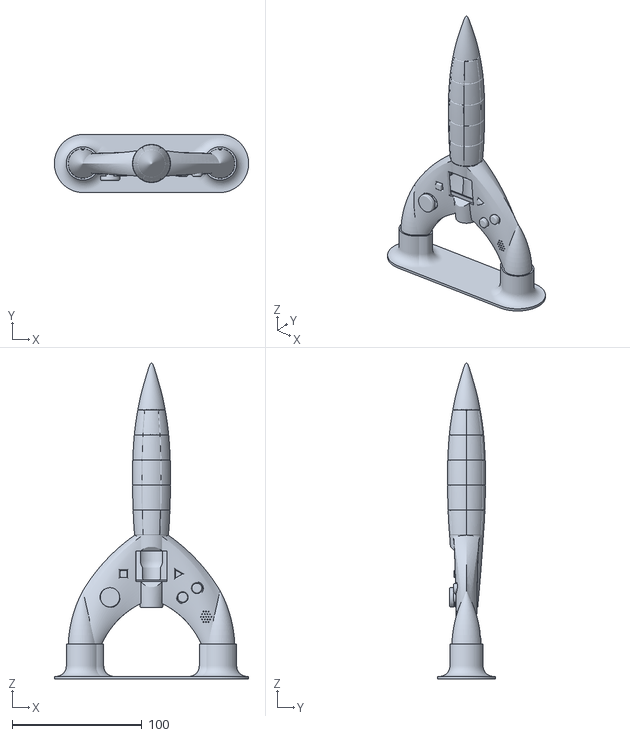
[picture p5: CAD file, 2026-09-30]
mechanics/stl/TintinRocketShooter.stl
150.0 x 45.0 x 243.9

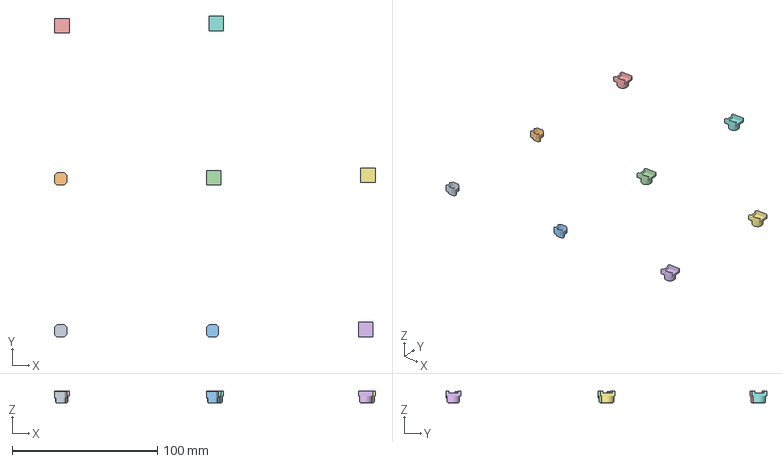
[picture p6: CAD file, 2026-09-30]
mechanics/print-profiles/LittleGameConsole/Buttons.3mf
220.8 x 220.8 x 8.30 mm
ControlButton.stl x 3
ActionButton.stl x 5

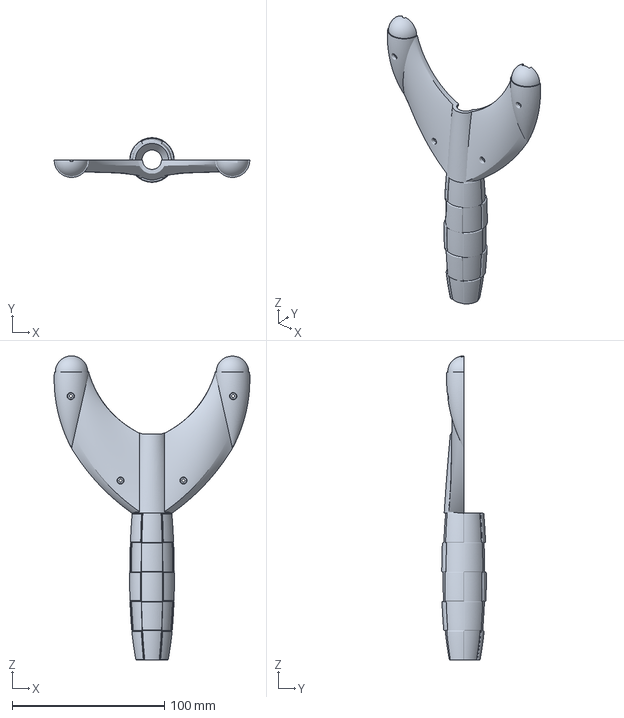
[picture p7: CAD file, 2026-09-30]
mechanics/print-profiles/TintinRocketShooter/RocketShooterLower.3mf
128.7 x 29.3 x 200.0 mm

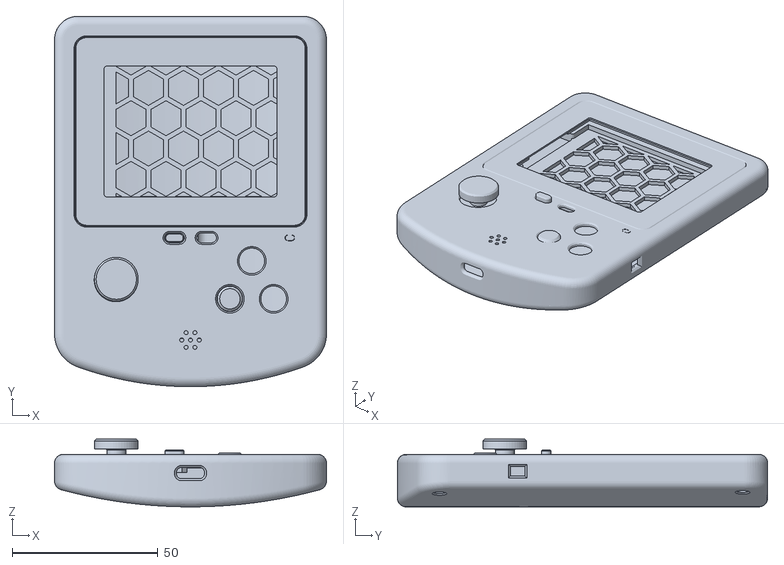
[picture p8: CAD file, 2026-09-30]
mechanics/stl/LittleGameConsole.stl
93.2 x 126.9 x 23.2

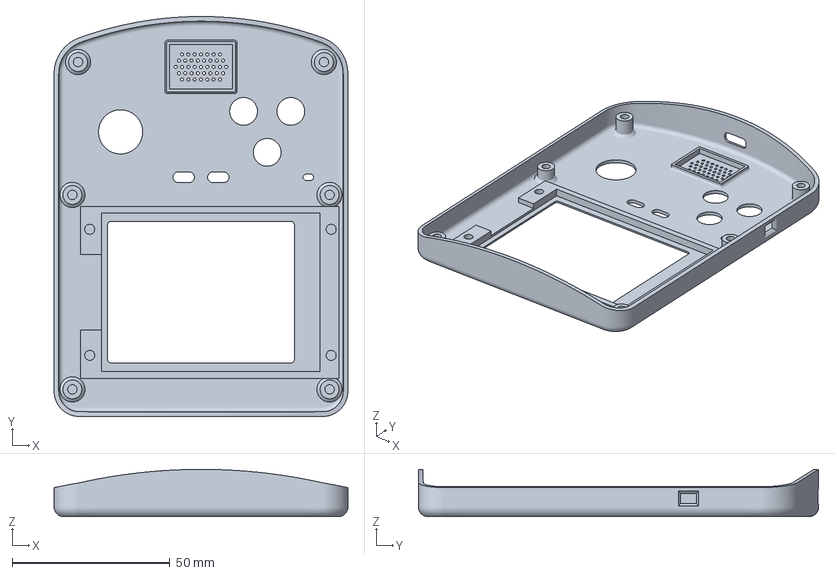
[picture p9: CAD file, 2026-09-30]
mechanics/print-profiles/LittleGameConsole/LittleGameConsole_Top0.2.3mf
93.2 x 126.9 x 15.0 mm

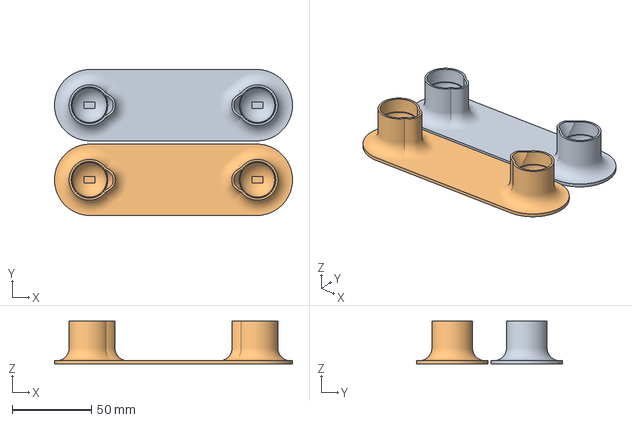
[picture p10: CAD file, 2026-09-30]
mechanics/print-profiles/TintinRocketShooter/Stand.3mf
150.0 x 92.0 x 27.0 mm
Stand.step x 2

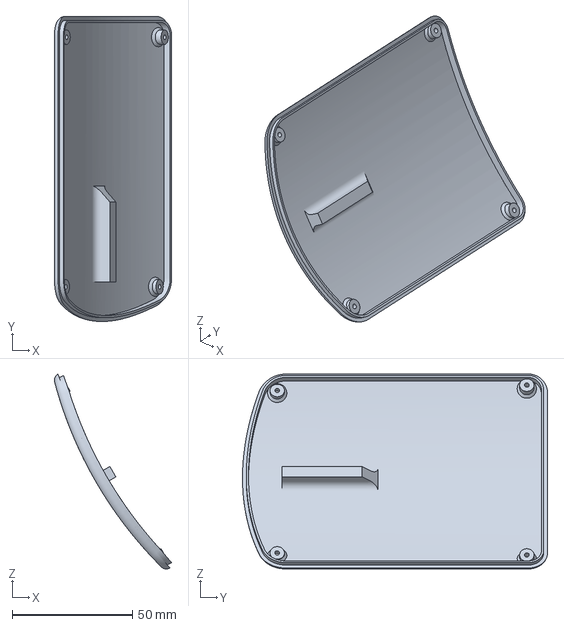
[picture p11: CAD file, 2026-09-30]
mechanics/print-profiles/LittleGameConsole/LittleGameConsole_Bottom_30Deg.3mf
48.8 x 126.9 x 81.1 mm

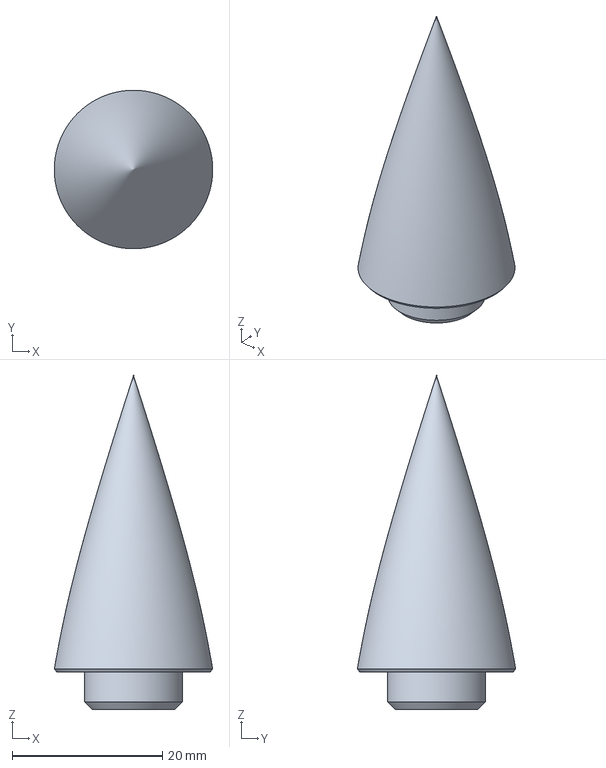
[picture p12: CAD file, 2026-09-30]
mechanics/print-profiles/TintinRocketShooter/TinTinRocket-Top-H2D-ABS-GF ABS-Support.3mf
21.1 x 21.1 x 44.4 mm

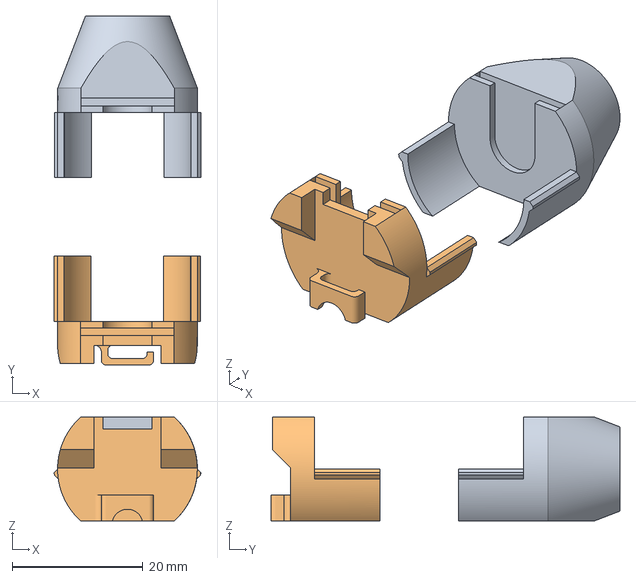
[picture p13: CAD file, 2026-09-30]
mechanics/print-profiles/TintinRocketShooter/Battery.3mf
22.5 x 53.5 x 15.9 mm
BatteryPlusEnd.stl
BatteryNegEnd.stl

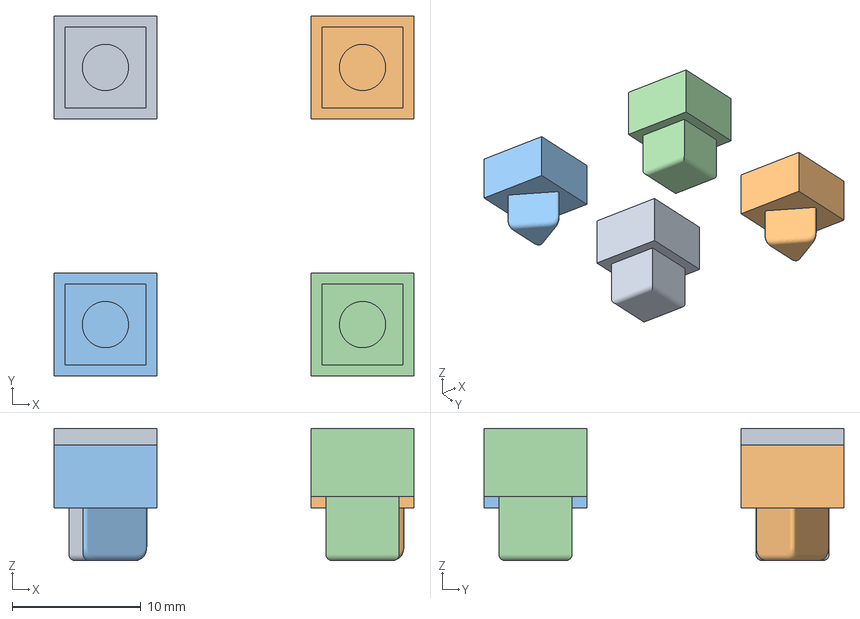
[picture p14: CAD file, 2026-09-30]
mechanics/print-profiles/TintinRocketShooter/SelectStartBtn.3mf
28.0 x 28.0 x 10.3 mm
SelectBtn.stl x 2
StartBtn.stl x 2

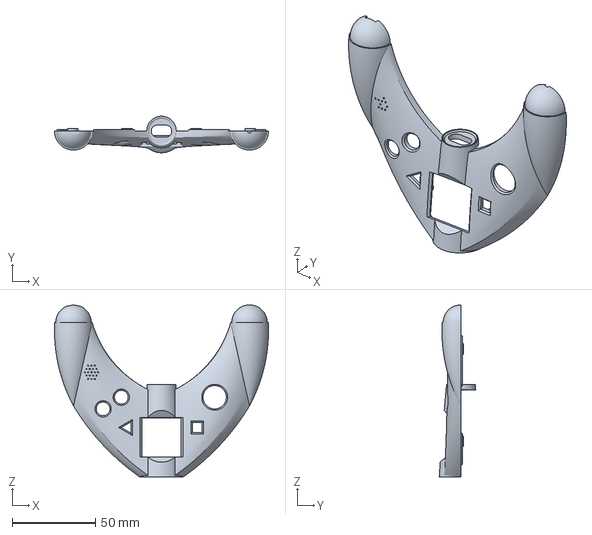
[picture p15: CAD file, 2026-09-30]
mechanics/print-profiles/TintinRocketShooter/TinTinRocket-Upper-H2D-PLA-GF Support.3mf
128.7 x 22.0 x 103.4 mm

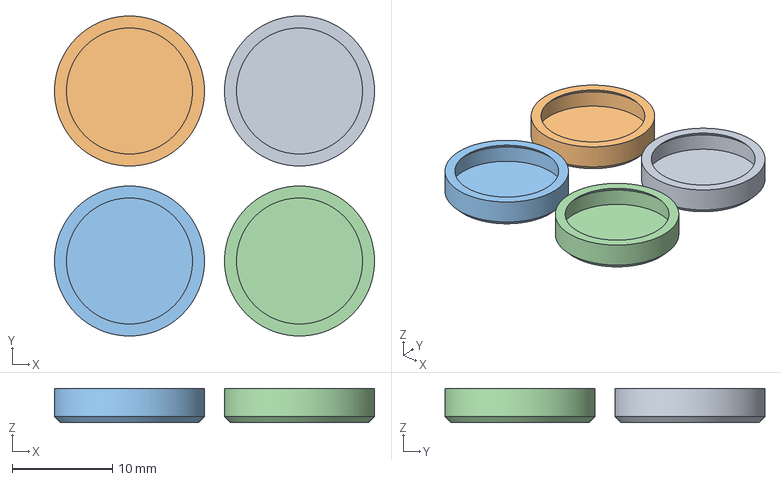
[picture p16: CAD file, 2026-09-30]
mechanics/print-profiles/TintinRocketShooter/JoyTopCover.3mf
32.0 x 32.0 x 3.40 mm
JoyTopCover.stl x 4

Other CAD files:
mechanics/print-profiles/TintinRocketShooter/TinTinRocket-Upper-H2D-ABS-GF ABS-Support.3mf
mechanics/print-profiles/TintinRocketShooter/TinTinRocket-Top-H2D-PLA-GF Support.3mf
mechanics/print-profiles/TintinRocketShooter/RocketShooterUpper.3mf
mechanics/print-profiles/TintinRocketShooter/RocketTop.3mf
mechanics/cad/LittleGameConsole.f3z

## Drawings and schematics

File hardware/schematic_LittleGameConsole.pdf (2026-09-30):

Drawn
VER

Create Date

PAGE | OF

Schematic

Update Date

SIZE

Page

2025-04-14

# 2025-04-14 LittleGameConsole

## Overview

# Hobbyist

## Christoph Streit

1 | A4

# Microcontroller

# Audio

Sheet: USB&Serial | Sheet: ESP32
2 | 3

# Sheet: Audio

5

I/O

# Sheet: Connectors / IO

6

# Power

# Sheet: Power

4

# USB to Serial USB

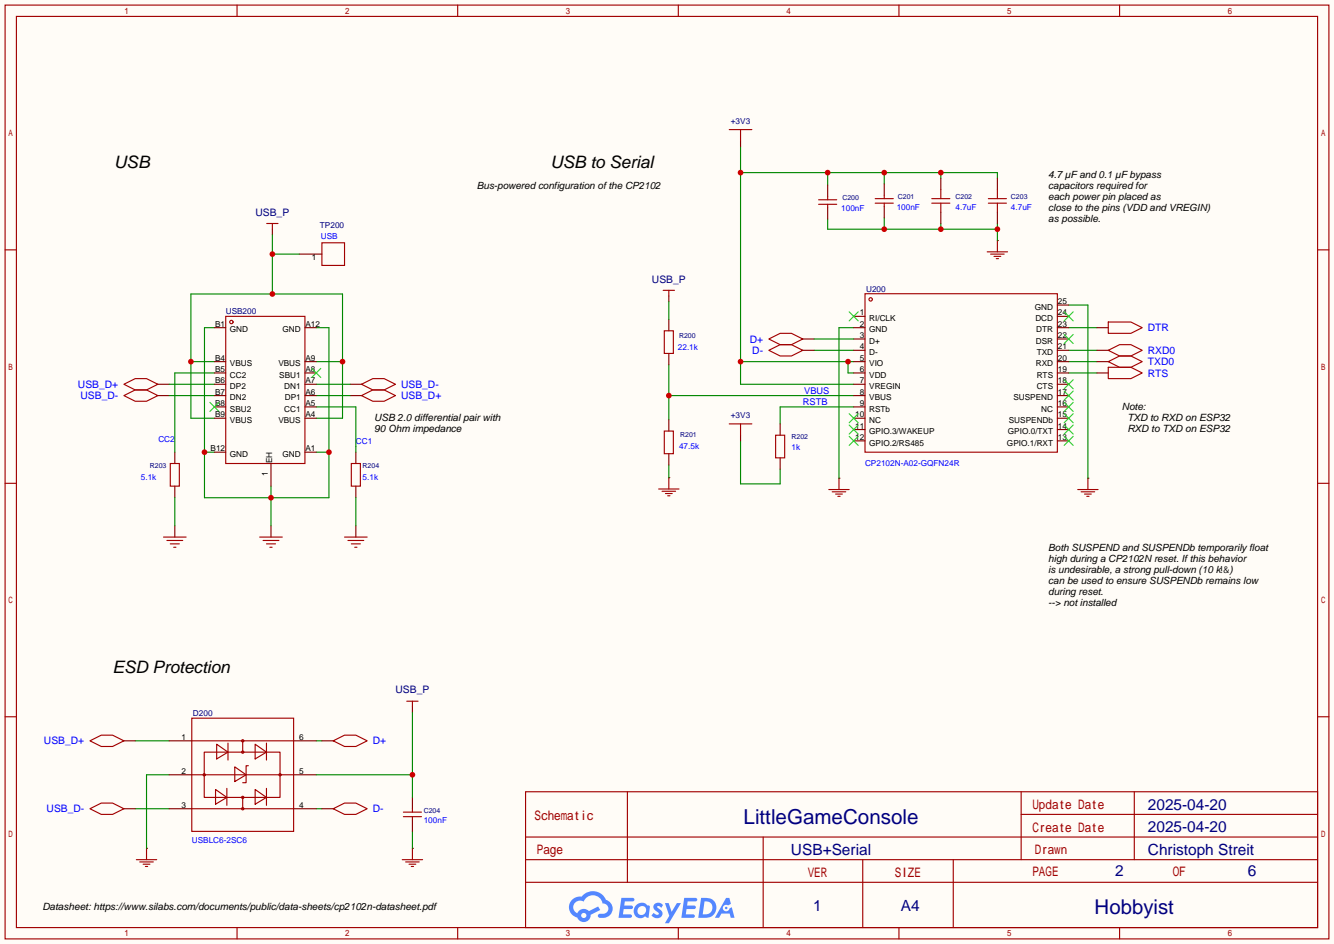
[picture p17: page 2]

4.7 µF and 0.1 µF bypass
capacitors required for
each power pin placed as
close to the pins (VDD and VREGIN)
as possible.

Bus-powered configuration of the CP2102

Note:
TXD to RXD on ESP32
RXD to TXD on ESP32

Both SUSPEND and SUSPENDb temporarily float
high during a CP2102N reset. If this behavior
is undesirable, a strong pull-down (10 k!&)
can be used to ensure SUSPENDb remains low
during reset.
--> not installed

Datasheet: https://www.silabs.com/documents/public/data-sheets/cp2102n-datasheet.pdf

# ESP32-PICO-MINI-02U

# NC 25 IO20 26 IO7 27 IO8 28 IO5 29 RXD0 30 TXD0 31 NC 32 IO19 33 IO22 34 IO21 35 GND 36

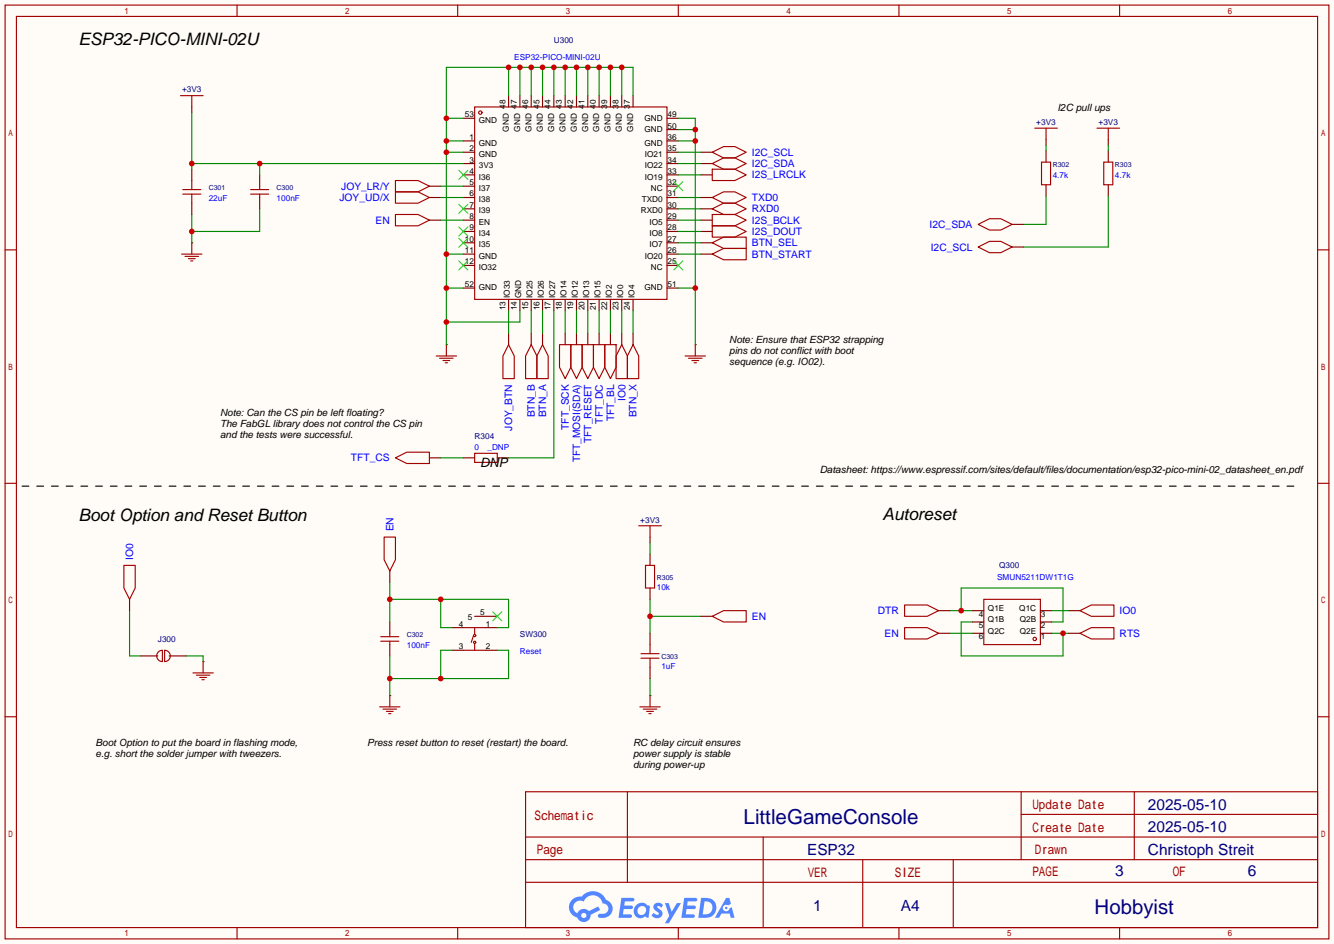
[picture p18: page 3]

Note: Ensure that ESP32 strapping
pins do not conflict with boot
sequence (e.g. IO02).

Note: Can the CS pin be left floating?
The FabGL library does not control the CS pin
and the tests were successful.

https://www.espressif.com/sites/default/files/documentation/esp32-pico-mini-02_datasheet_en.pdf

Boot Option to put the board in flashing mode,
e.g. short the solder jumper with tweezers.

Press reset button to reset (restart) the board.

RC delay circuit ensures
power supply is stable
during power-up

# Automatic Switchover

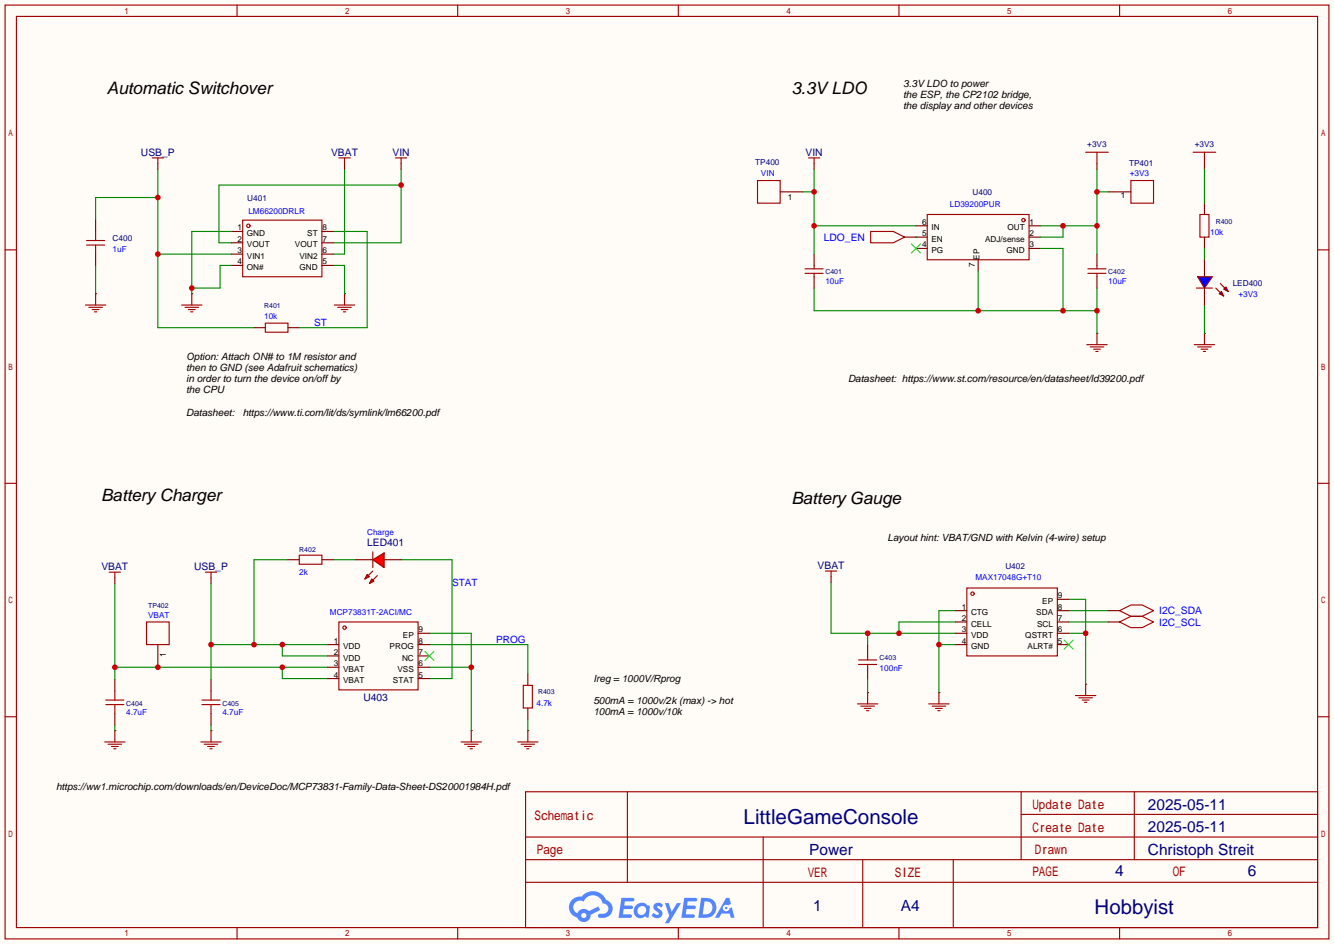
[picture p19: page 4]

the ESP, the CP2102 bridge,
the display and other devices

Option: Attach ON# to 1M resistor and
then to GND (see Adafruit schematics)
in order to turn the device on/off by
the CPU
Datasheet: https://www.ti.com/lit/ds/symlink/lm66200.pdf

Datasheet: https://www.st.com/resource/en/datasheet/ld39200.pdf

Layout hint: VBAT/GND with Kelvin (4-wire) setup

https://ww1.microchip.com/downloads/en/DeviceDoc/MCP73831-Family-Data-Sheet-DS20001984H.pdf

## Gain Selection

## Amplifier

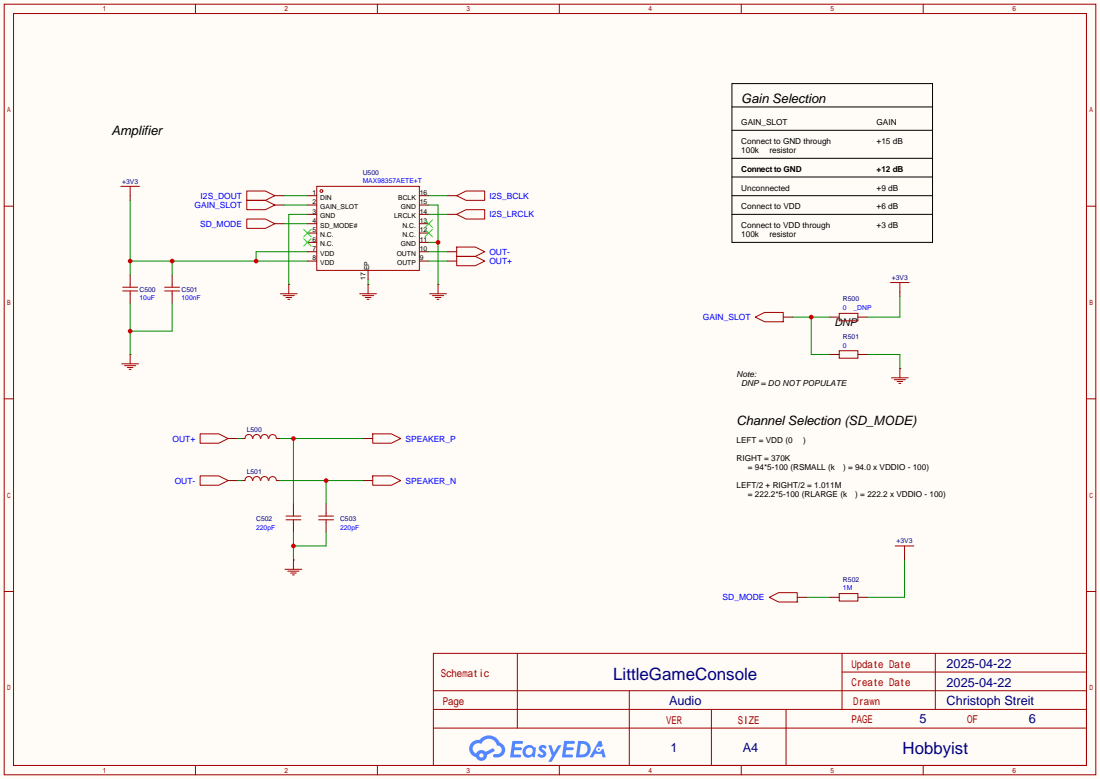
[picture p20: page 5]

Connect to GND through
100k resistor
Connect to GND
Unconnected
Connect to VDD
Connect to VDD through

Note:
DNP = DO NOT POPULATE

Display | On/Off | M2 Mounting Holes

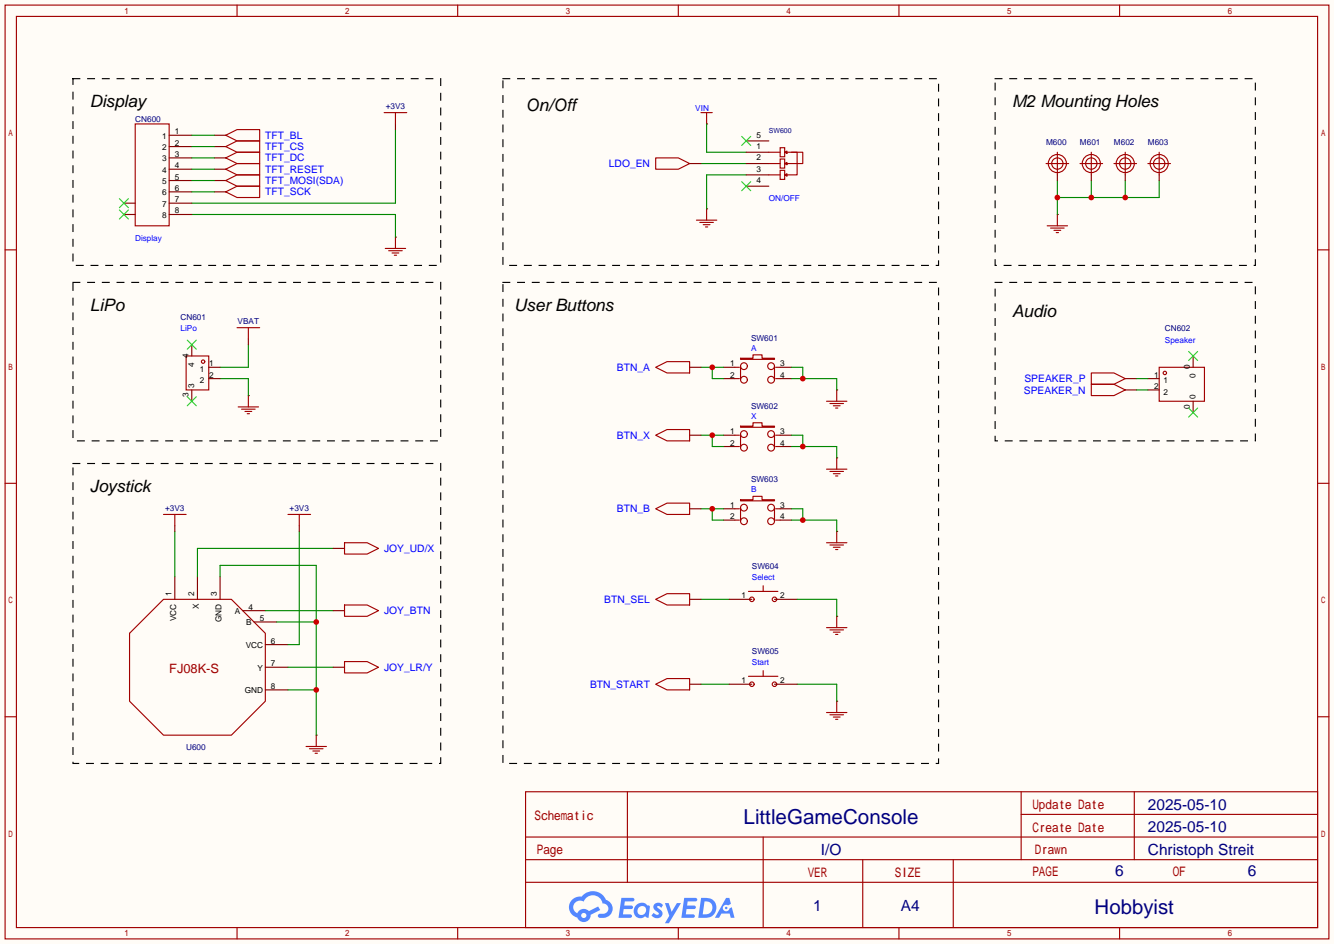
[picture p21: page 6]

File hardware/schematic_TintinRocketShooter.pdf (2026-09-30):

A | A
B | B
C | C
D | D

## TITLE: REV:

## Date:

## Sheet: Drawn By:

## Company:

RocketShooter_from_STD | 1.0

2023-06-25

christoph.streit

Hobbyist

# Microcontroller

# Audio

Sheet: USB&Serial | Sheet: ESP32

# [1] Overview

2 | 3

# IMU

6

Sheet: Audio | Sheet: IMU

5

I/O

# Sheet: Connectors / IO

7

4

# Sheet: Power

# Power

# Sheet: Power

4

# 3.3V LDO

# [4] Power

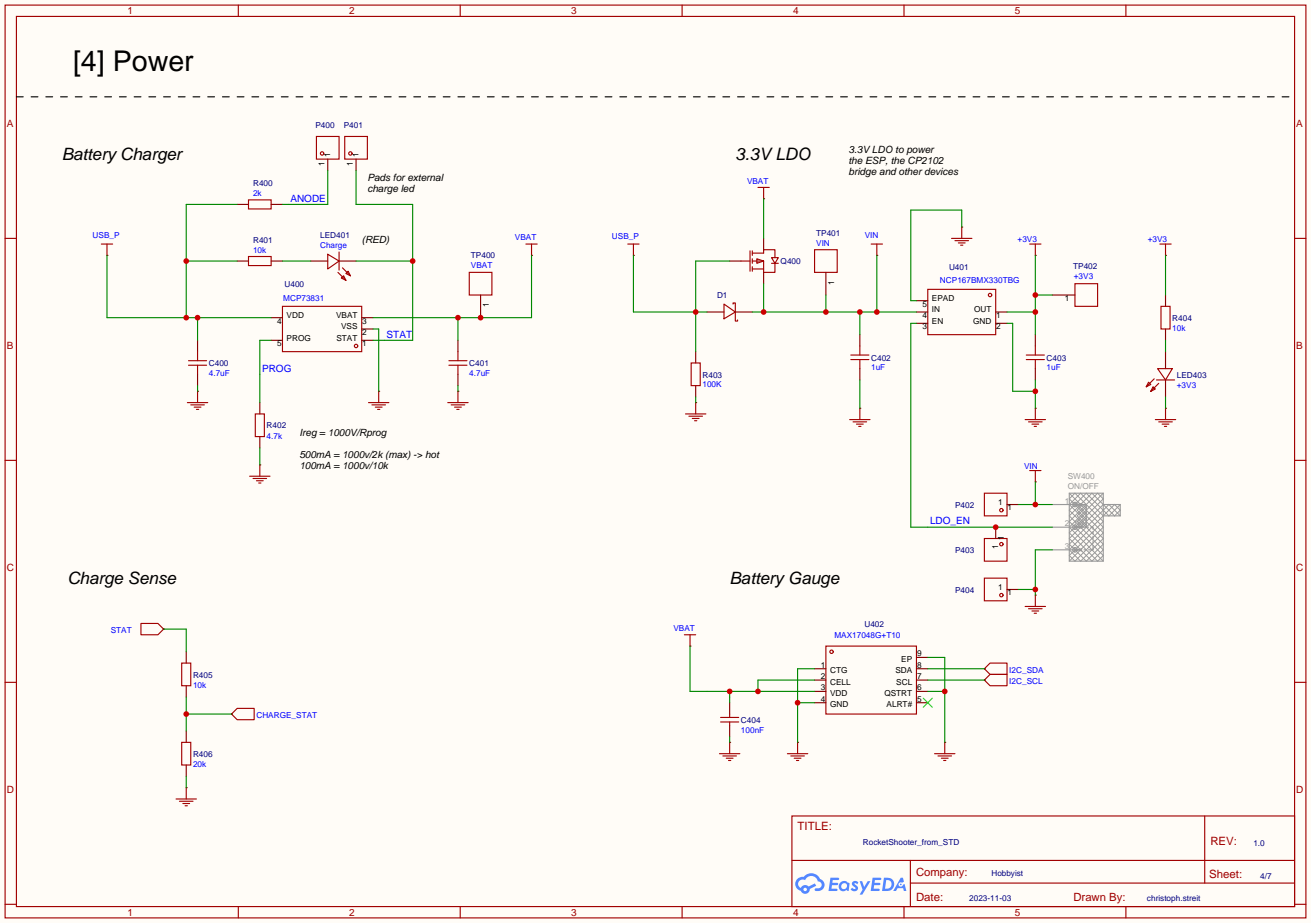
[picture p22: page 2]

3.3V LDO to power
the ESP, the CP2102
bridge and other devices

# [5] Audio

# Gain Selection

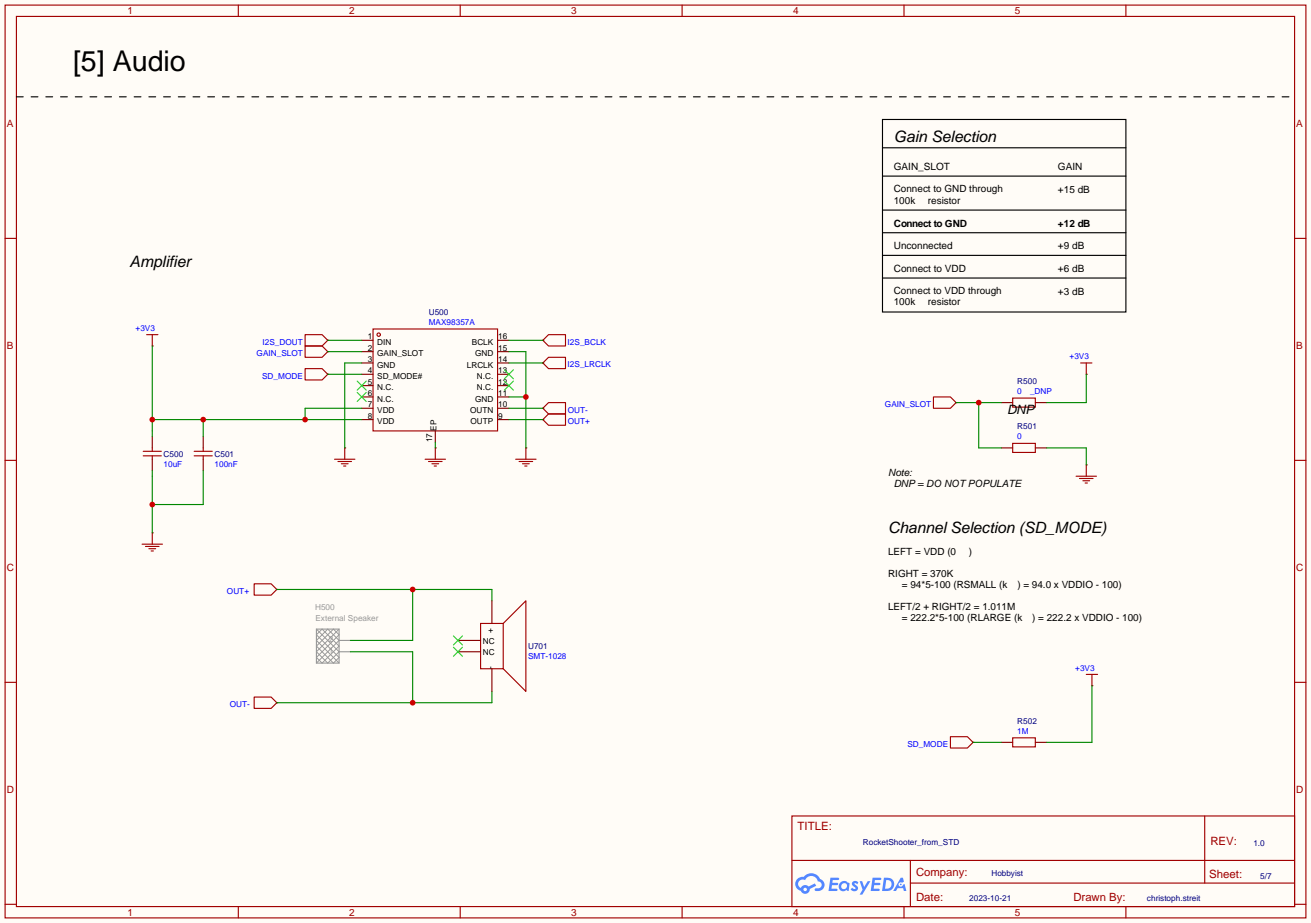
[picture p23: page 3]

Connect to GND through
100k resistor
Connect to GND
Unconnected
Connect to VDD
Connect to VDD through

Note:
DNP = DO NOT POPULATE

USB | USB to Serial

# [2] USB & Serial Bridge

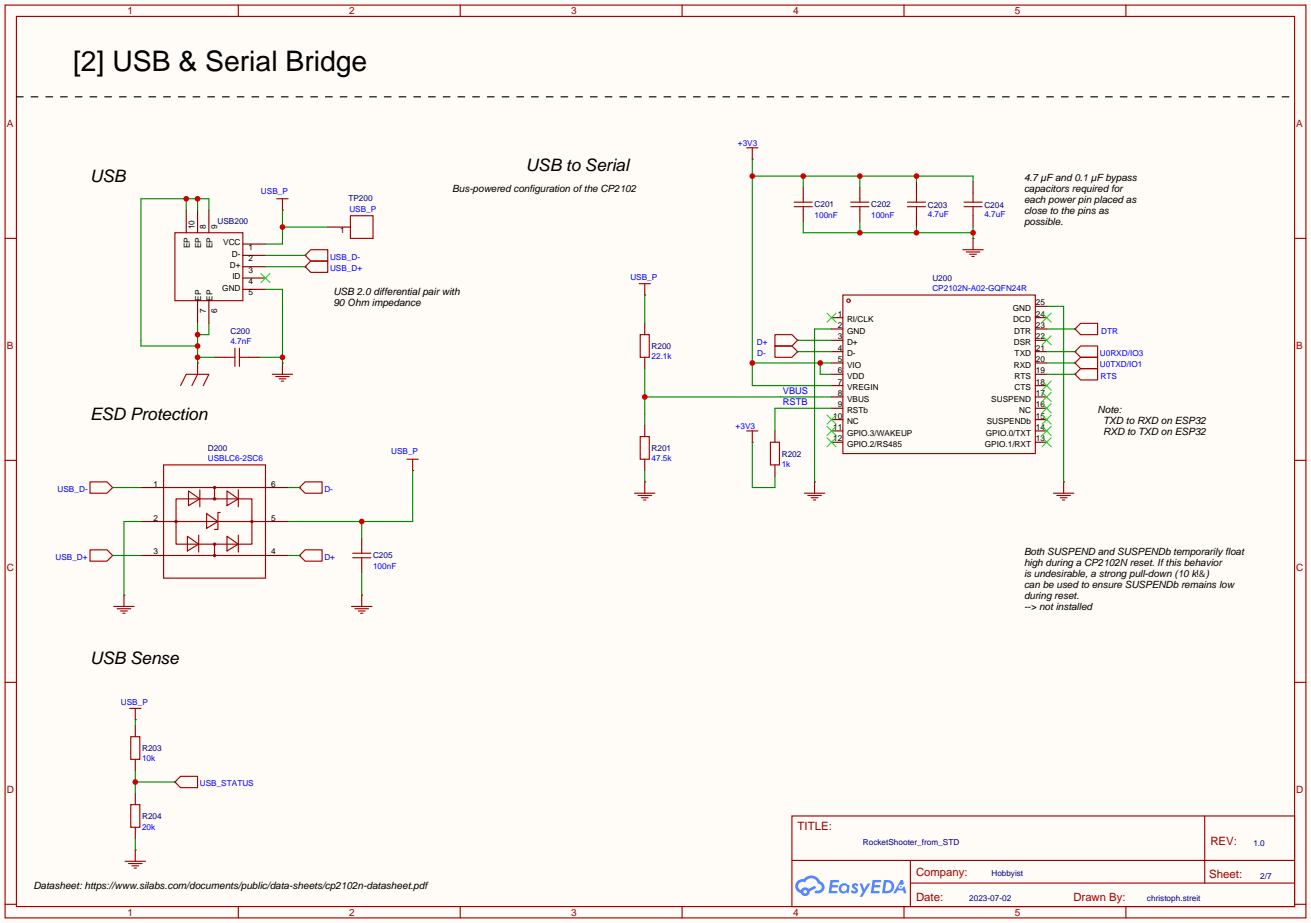
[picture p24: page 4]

4.7 µF and 0.1 µF bypass
capacitors required for
each power pin placed as
close to the pins as
possible.

Bus-powered configuration of the CP2102

Note:
TXD to RXD on ESP32
RXD to TXD on ESP32

Both SUSPEND and SUSPENDb temporarily float
high during a CP2102N reset. If this behavior
is undesirable, a strong pull-down (10 k!&)
can be used to ensure SUSPENDb remains low
during reset.
--> not installed

Datasheet: https://www.silabs.com/documents/public/data-sheets/cp2102n-datasheet.pdf

# ESP32 PICO V3-02

# [3] ESP32

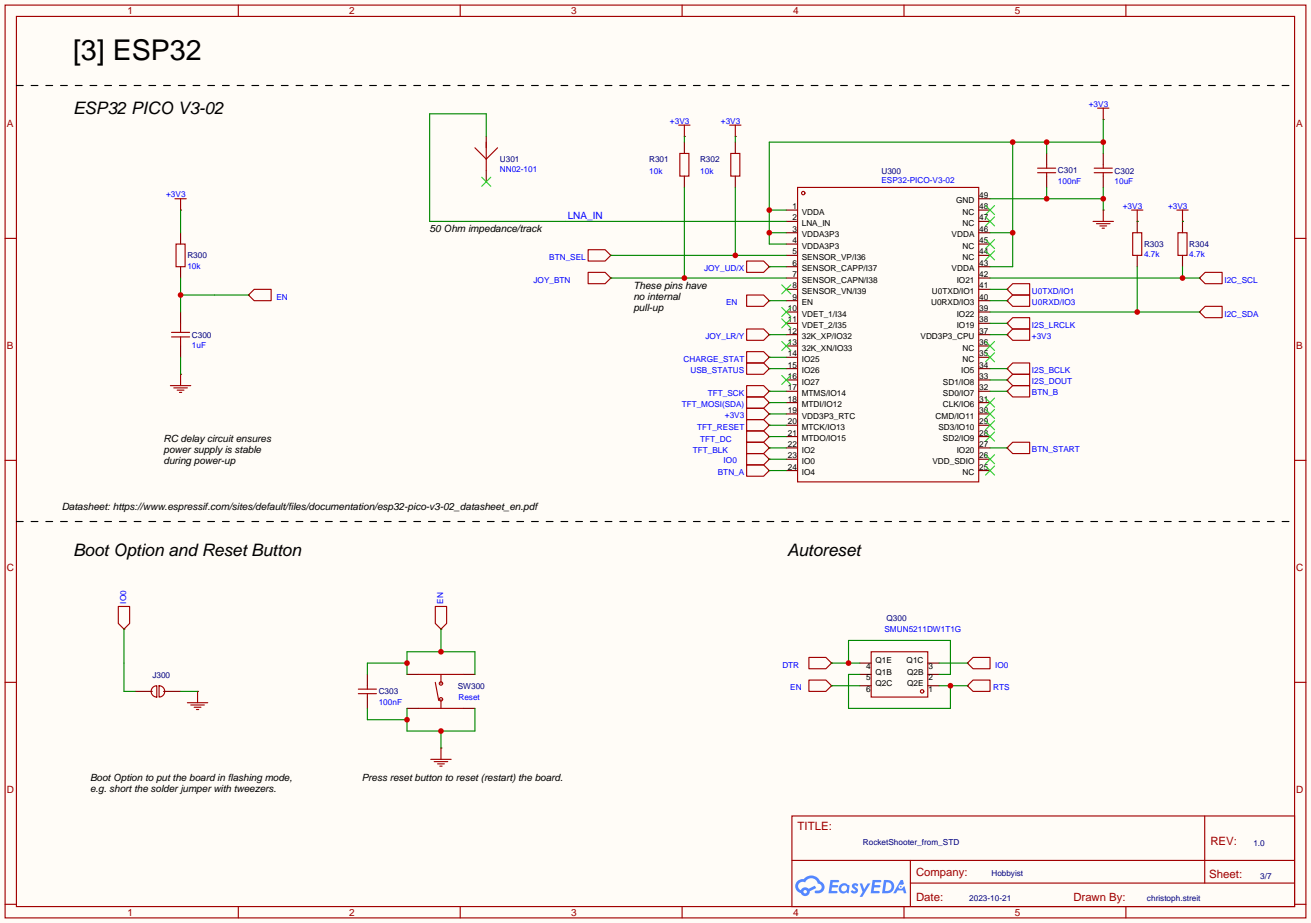
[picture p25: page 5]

RC delay circuit ensures
power supply is stable
during power-up

Datasheet: https://www.espressif.com/sites/default/files/documentation/esp32-pico-v3-02_datasheet_en.pdf
Boot Option and Reset Button

Boot Option to put the board in flashing mode,
e.g. short the solder jumper with tweezers.

Press reset button to reset (restart) the board.

# [7] Connectors / IO

Display | User Buttons

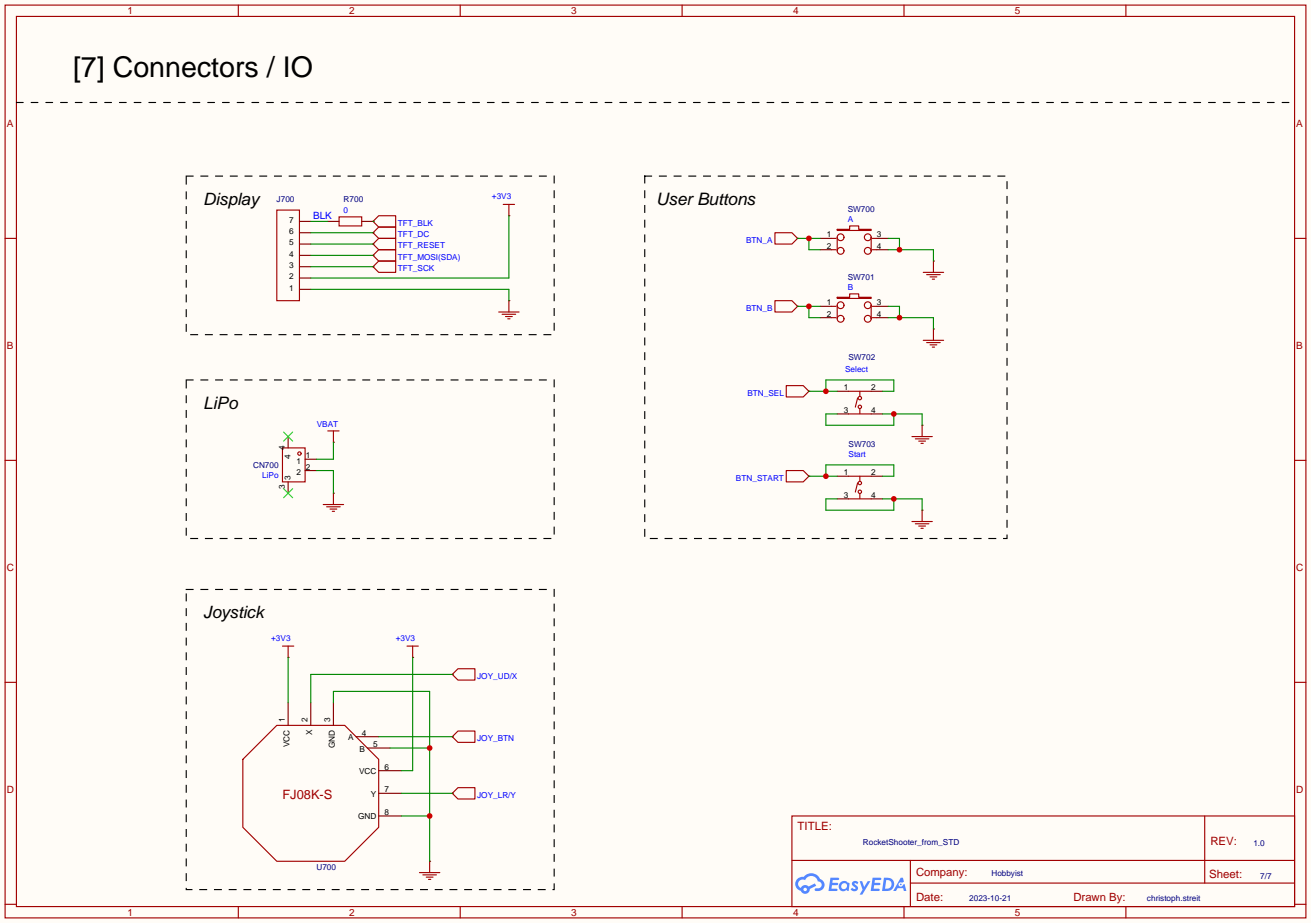
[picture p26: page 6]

# [6] IMU

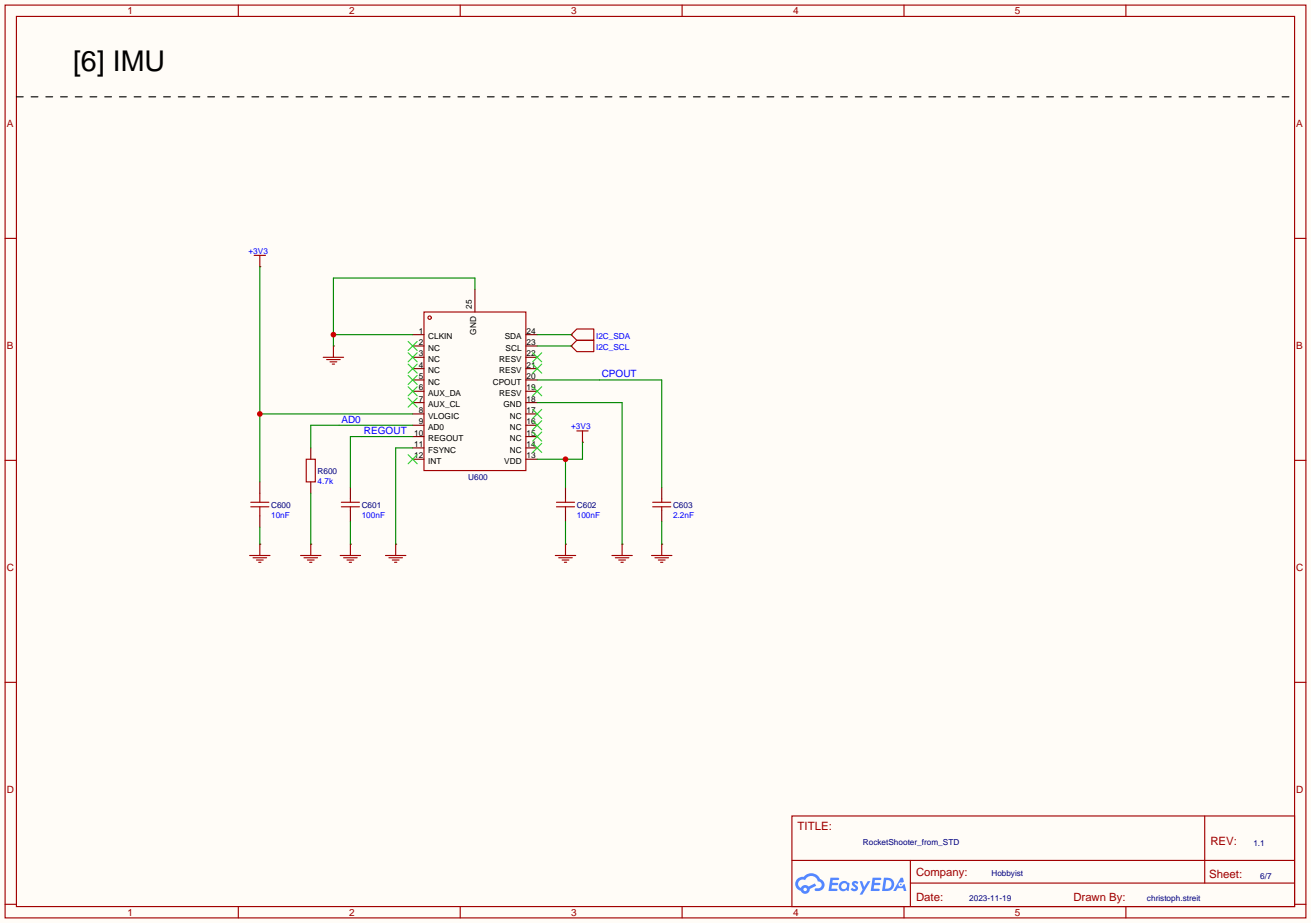
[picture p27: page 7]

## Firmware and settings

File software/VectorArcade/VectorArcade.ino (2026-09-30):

// ---------------------------------------------------------------------------------------------
// VectorArcade - Asteroids and Lunar Lander, the 1979 vector arcade classics, on a small
//                ESP32 game console with a TFT display, an analog joystick and buttons.
//                One code base for two boards, selected in BoardSelect.h:
//                  LittleGameConsole   - 2.8" 320x240 display, five buttons
//                  TintinRocketShooter - 240x240 display in a Tintin rocket, four buttons and an IMU
//           
// Christoph Streit - 2025-2026
// ---------------------------------------------------------------------------------------------

// #pragma GCC optimize ("O2")

#include <Streaming.h>
#include <WiFi.h>
#include <SPI.h>
#include <Wire.h>
#include <LittleFS.h>
#include <esp_partition.h>
#include <sstream>
#include <iomanip>

// ---- Gauge

#include "Adafruit_MAX1704X.h"
#include "BatteryStatus.h"

Adafruit_MAX17048 fuelGauge;

// ---- Display

#include "fabgl.h"
#include "Board.h"
#include "Layout.h"
#include "Version.h"
#include "SoundClips.h"

#pragma message("VectorArcade " VECTORARCADE_VERSION ": building for " BOARD_NAME ", sounds " SOUNDS_SOURCE)

#if BOARD_TFT_INVOFF()
// FabGL inverts the colors by default -> switch inversion off (INVOFF)
#ifndef ST7789_INVOFF
#define ST7789_INVOFF     0x20
#endif

class ST7789ControllerINVOFF : public fabgl::ST7789Controller {
protected:
  void softReset() override 
  {
    fabgl::ST7789Controller::softReset();
    SPIBeginWrite();
    writeCommand(ST7789_INVOFF);
    SPIEndWrite();
  }
};

ST7789ControllerINVOFF DisplayController;
#else
fabgl::ST7789Controller DisplayController;
#endif
fabgl::Canvas canvas(&DisplayController);

// ---- Menu

#include "Menu.h"
#include "MenuItem.h"
#include "MenuPage.h"
#include "FPSToggle.h"
#include "SoundVolume.h"
#include "JoystickCalibration.h"
#include "WipeAndReset.h"
#include "LunarLander.h"
#include "Asteroids.h"

Menu m(canvas);
FPSToggle* fpsToggle = nullptr; // Owned by the menu

#if BOARD_HAS_IMU()
// ---- IMU

#include <Wire.h>
#include <MPU6050_light.h>
#include "IMUStatus.h"
#include "IMUCalibration.h"

MPU6050 imu(Wire);
#endif

//----------------------------------------------------------------------------------------------
void setup()
{
#if BOARD_HAS_BACKLIGHT()
  pinMode(cTFT_BL, OUTPUT);
  digitalWrite(cTFT_BL, LOW); // Backlight off
#endif

  Serial.begin(115200); // Used for info/debug

  // On a classic ESP32 Serial is a UART and is ready as soon as begin() returns. With native
  // USB (e.g. ESP32-S3 USB CDC) it only becomes true once a host has opened the port: wait
  // briefly so the startup messages are not lost, but never block boot without a host.
  const unsigned long serialWaitStart = millis();
  while (!Serial && millis() - serialWaitStart < 1000)
  {
    delay(10);
  }

  Serial << "VectorArcade " << VECTORARCADE_VERSION << " for " << BOARD_NAME << endl;
  Serial << "Built " << __DATE__ << " " << __TIME__ << endl;
  Serial << "Sounds " << SOUNDS_SOURCE << endl;

  WiFi.mode(WIFI_OFF);
  Wire.begin(cI2C_SDA, cI2C_SCL);

  // ---- Display

  DisplayController.begin(cSPI_SCK, cSPI_MOSI, cTFT_DC, cTFT_RESET, -1, BOARD_TFT_SPI_HOST);
  DisplayController.setResolution(BOARD_TFT_RESOLUTION, -1, -1, true);
  DisplayController.setOrientation(BOARD_TFT_ORIENTATION);

  // Clear screen
  canvas.setBrushColor(Color::Black);
  canvas.clear();
  canvas.swapBuffers();

#if BOARD_HAS_BACKLIGHT()
  digitalWrite(cTFT_BL, HIGH); // Backlight on
#endif

  // ---- Gauge 

  if (fuelGauge.begin() == false) 
  {
    Serial << "Couldn't find MAX17048\nMake sure a battery is plugged in!" << endl;
  }
  delay(500);
  // fuelGauge.quickStart();

#if BOARD_HAS_IMU()
  // ---- IMU

  byte imuStatus = imu.begin();
  if (imuStatus != 0)
  {
    Serial << "Couldn't find MPU6050 (status " << imuStatus << ")" << endl;
  }

#endif
#if SOUNDS_FROM_LITTLEFS()
  // ---- Filesystem (sound clips)

  // The partition labelled "littlefs" (partitions.csv) holds a LittleFS image. Its subtype is
  // still "spiffs": ESP-IDF 4.4 has no LittleFS subtype, and LittleFS finds the partition by
  // label. begin(false) never formats on its own: a partition that cannot be mounted (never
  // formatted, or another filesystem) is formatted here, explicitly and reported. A missing
  // partition (wrong partition table) is only reported.
  const char* cFSPartition = "littlefs";

  if (esp_partition_find_first(ESP_PARTITION_TYPE_DATA, ESP_PARTITION_SUBTYPE_ANY, cFSPartition) == nullptr)
  {
    Serial << "LittleFS: no partition \"" << cFSPartition << "\" - check partitions.csv" << endl;
  }
  else if (LittleFS.begin(false, "/littlefs", 10, cFSPartition) == false)
  {
    Serial << "LittleFS: partition cannot be mounted - formatting it as LittleFS" << endl;
    if (LittleFS.format() == true && LittleFS.begin(false, "/littlefs", 10, cFSPartition) == true)
    {
      Serial << "LittleFS: formatted and mounted, " << LittleFS.totalBytes() << " bytes" << endl;
    }
    else
    {
      Serial << "LittleFS: formatting failed" << endl;
    }
  }
  checkSoundFiles();
#endif

  // ---- Menu

#if BOARD_HAS_IMU()
  m.addMenu(new LunarLander(m, imu));
#else
  m.addMenu(new LunarLander(m));
#endif
  m.addMenu(new Asteroids(m));

  MenuPage* p = new MenuPage(m, "Configuration");
    p->add(new JoystickCalibration(m));
#if BOARD_HAS_IMU()
    p->add(new IMUCalibration(m, imu));
#endif
    p->add(new SoundVolume(m));
    p->add(new WipeAndReset(m));
  m.addMenu(p);

  fpsToggle = new FPSToggle(m);
  m.addMenu(fpsToggle);
  m.addObject(new BatteryStatus(canvas, fuelGauge));
#if BOARD_HAS_IMU()
  m.addObject(new IMUStatus(canvas, imu));
#endif
  m.begin();
}

//----------------------------------------------------------------------------------------------
void loop()
{
  // Animation steps: at most "targetFPS" frames per second are rendered
  const unsigned long targetFPS = 25;
  const unsigned long dt = 1000 / targetFPS;

  int64_t t0, t1; // To compute the rendering time of one frame
  int delayMS;    // and to delay if we are too fast

  while (true)
  {
    // ---- Compute FPS each second

    static int64_t stime  = esp_timer_get_time();
    static int FPS        = 0;
    static int FPSCounter = 0;

    if (esp_timer_get_time() - stime > 1000000) 
    {
      FPS = FPSCounter;
      stime = esp_timer_get_time();
      FPSCounter = 0;
    }
    ++FPSCounter;

    // ---- Update frame and redraw

    t0 = esp_timer_get_time();  // us

    m.step(dt);
    m.draw();
    
    if (fpsToggle->isOn())
    {
      canvas.setGlyphOptions(GlyphOptions().FillBackground(true));
      canvas.setPenColor(cDefaultCol);
      canvas.setBrushColor(Color::Black);    
      canvas.selectFont(&fabgl::FONT_6x8);
      canvas.drawTextFmt(Layout::cFPSPosX, Layout::cFPSPosY, " %d FPS ", FPS);
    }

    canvas.swapBuffers();

    t1 = esp_timer_get_time();  // us
    delayMS = (dt - (t1 - t0) / 1000);
    if (delayMS > 0)
      vTaskDelay(delayMS / portTICK_PERIOD_MS);
  }
}

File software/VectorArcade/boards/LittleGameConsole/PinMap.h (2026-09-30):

// Single source of truth for every GPIO used in the project
#pragma once

// Strapping pins - the ESP32 latches GPIO 0, 2, 5, 12 and 15 at reset. This board uses four:
//
// GPIO 12 (cSPI_MOSI) is the MTDI strapping pin: its level is latched at reset and selects the
// flash voltage, where high means 1.8 V. With 3.3 V flash the board will not boot if this pin
// is high at reset. Safe here because SPI MOSI idles low. Do not fit a pull-up to this line.
//
// GPIO 2 (cTFT_BL) must be low or floating at reset for the serial bootloader to be entered,
// so a backlight circuit that pulls it high can break flashing. setup() drives it low before
// anything else runs. Do not fit a pull-up to this line.
//
// GPIO 15 (cTFT_DC) is the MTDO strapping pin (boot log and SDIO timing) - harmless here.
// GPIO 5 (cI2S_BCLK) is a strapping pin (SDIO timing) - harmless here.

// SPI (display)
constexpr int cSPI_SCK   = 14;  // SPI clock pin
constexpr int cSPI_MISO  = -1;  // Not used
constexpr int cSPI_MOSI  = 12;  // SPI Microcontroller Out Serial In pin (often named SDA)

// Display
constexpr int cTFT_DC    = 15;  // SPI data or command selector pin
constexpr int cTFT_RESET = 13;  // TFT reset pin
constexpr int cTFT_BL    = 2;   // TFT backlight pin

// I2C (fuel gauge)
constexpr int cI2C_SDA   = 22;
constexpr int cI2C_SCL   = 21;

// I2S (audio)
constexpr int cI2S_DOUT  = 8;   // I2S data out pin
constexpr int cI2S_BCLK  = 5;   // Bit clock
constexpr int cI2S_LRC   = 19;  // Left/Right clock, also known as Frame clock or word select

// Buttons
constexpr int cPinBtnA     = 26;
constexpr int cPinBtnB     = 25;
constexpr int cPinBtnAux   = 4;
constexpr int cPinBtnSel   = 7;
constexpr int cPinBtnStart = 20;

// Joystick
constexpr int cPinJoyBtn = 33;
constexpr int cPinJoyX   = 37;
constexpr int cPinJoyY   = 38;

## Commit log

2026-09-30 reset button problem detailed
2026-09-30 print-profile "disclaimer" added
2026-09-30 Joystick: validate calibration, clamp output, improved direction logic
2026-09-30 Joystick calibration: position field and axis sliders
    Shows the joystick position, the range covered so far and per-axis
    sliders during the min/max calibration, and reports an axis that was
    not moved. setCalibrationData() now returns which axes were accepted.
2026-10-11 Joystick calibration: center averaged over four guided releases
2026-10-13 Asteroids: draw the splash pages once instead of every frame
2026-10-13 Calibration: keep text and progress bar clear of the FPS counter; ignore *.log
2026-10-14 Sel cancels Wipe & Reset and the IMU calibration countdown
2026-10-14 Physics in per-second units; advance the games by the measured frame time
2026-10-14 Wipe & Reset: centre the Yes/No buttons
2026-10-14 Joystick calibration: automatic releases, range circle
2026-10-16 Menu buttons and volume bar: frames with closed corners
2026-10-18 Print profiles: one naming scheme, duplicate PLA-GF project removed
2026-10-18 Hardware: BOMs of both boards added
2026-10-18 Low-battery warning and "battery empty" screen
    - The battery icon's last segment blinks below 1 %; the low-charge red is brighter
    - Battery empty when the gauge has shown 0 % or the voltage has been below 3.20 V
    for one minute: a running game is stopped and a full screen asks to charge the
    console or switch it off; it returns to the menu once the gauge shows 2 %
    - The gauge is read every 5 s, also during games
    - README: battery behaviour
2026-10-18 Battery charge in percent and a charging animation
2026-10-27 Hardware: charge sense through a level shifter instead of three-state STAT
2026-10-31 Rename the Aux button to X
    The fifth button follows the A, B, X naming of common controllers
